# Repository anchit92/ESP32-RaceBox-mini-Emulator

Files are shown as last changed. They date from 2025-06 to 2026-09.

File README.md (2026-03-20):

# Open Source RaceBox Mini Emulator
> **Disclaimer:** This project is independent and open-source. It is not affiliated with, endorsed by, or officially connected to RaceBox. The name “RaceBox Mini” is used only to describe compatibility.

## Overview

This project provides firmware for an ESP32-based device that acts as a high-performance GPS/IMU Bluetooth Low Energy (BLE) broadcaster. It integrates a U-blox GNSS module for precise position, velocity, and timing data at 25Hz, along with an MPU6050 accelerometer and gyroscope for motion sensing.

The device is designed to be housed in a custom 3D-printed enclosure, with design files included in this repository.

---

> [!TIP]
> **Other Hardware Options**  
> Check Out The [Mods Folder](./Mods) For Other Hardware Options.
> For new builds, check out the [PCB version](./Mods/anchit92/PCB_version).

---

## Features

- **High-Resolution GPS Data**: Achieves 25Hz update rate using a U-blox GNSS module.  
- **Multi-Constellation Support**: Leverages GPS, Galileo, GLONASS, and BeiDou for enhanced accuracy and reliability.  
- **Integrated IMU**: Captures 3-axis accelerometer (`±8g`) and 3-axis gyroscope (`±500 deg/s`) data from the MPU6050.  
- **Real-time BLE Streaming**: Transmits a custom 88-byte data packet containing comprehensive GNSS and IMU information over BLE.  
- **Automatic Configuration**: Robust GPS initialization.
- **Custom RaceBox Protocol**: Data is encapsulated in a UBX-like custom protocol for efficient transmission.  
- **3D Printable Enclosure**: Includes design files for a compact and protective case.  

---

## Bill of Materials (BOM)

To build this project, you'll need the following components:

- **ESP32 Development Board**: (https://a.co/d/fTThpTl)  
- **U-blox GNSS Module**: 
  * MG-902 - https://a.co/d/b6DcUS6 
  * SAM-M10Q - https://a.co/d/54zrba3
  * MG-903 - https://a.co/d/fxp2tLk 
  * HGLRC M100-5883 - https://a.co/d/47V0TqJ
  * AERO SELFIE M10G-5883L- https://a.co/d/cmYLjBP (Theoretically works but I dont have it)
    
  Any M10 based U-blox modules should work, the output rate may vary but you should be able to get 25hz with just GPS enabled. But YMMV.
  
- **MPU6050 Accelerometer/Gyroscope Module**: (https://a.co/d/dCMwffg or similar)  
- **24AWG Hook-up Wire/Jumper Wires** or just use the wiring that comes with GNSS module, its perfect for this application.
- **M3x6 Screws** (2)    
- **Soldering Iron & Solder**
- **USB-C or Micro-USB Cable** (Depending on your ESP32 board, But USB-C all the things)  
- **3D Printer & ABS Filament**  

The electronics should cost under 40$. 

---

## Assembly Instructions

### Wire the Components, load the firmware and test them outdoors.

**ESP32 <--> U-blox GNSS Module:**
- ESP32 GPIO 16 (RX2) <--> GNSS TX  
- ESP32 GPIO 17 (TX2) <--> GNSS RX  
- ESP32 5V or 3.3V <--> GNSS VCC *(check voltage requirements)*  
- ESP32 GND <--> GNSS GND  

**ESP32 <--> MPU6050:**
- ESP32 GPIO 21 (SDA) <--> MPU6050 SDA  
- ESP32 GPIO 22 (SCL) <--> MPU6050 SCL  
- ESP32 5V or 3.3V <--> MPU6050 VCC *(check voltage requirements)*
- ESP32 GND <--> MPU6050 GND  

---

### Prepare the 3D Printed Case

- You shouldn't need any post processing of the printed parts but make sure the buttons slide smoothly in the holes in the lid

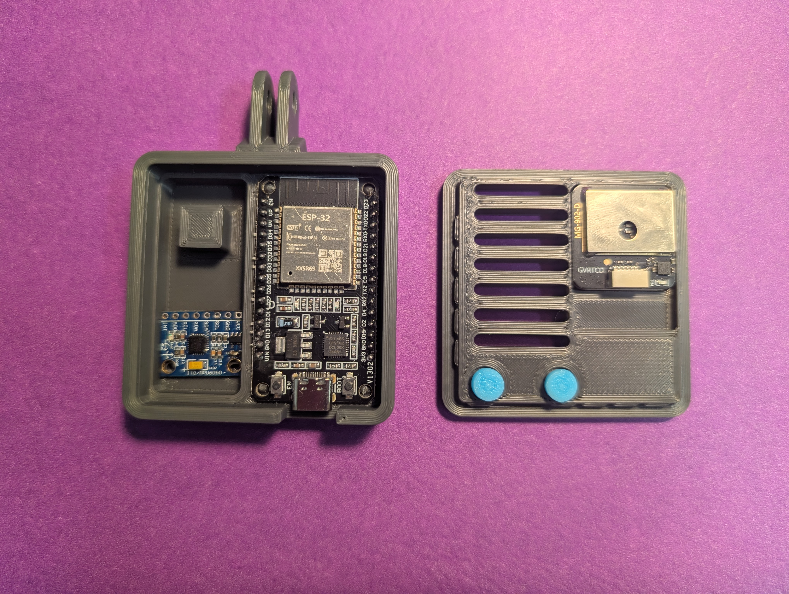
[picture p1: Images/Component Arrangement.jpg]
image info Component arrangement


### Enclose the Electronics

- Mount the MPU6050 module using M3 screws
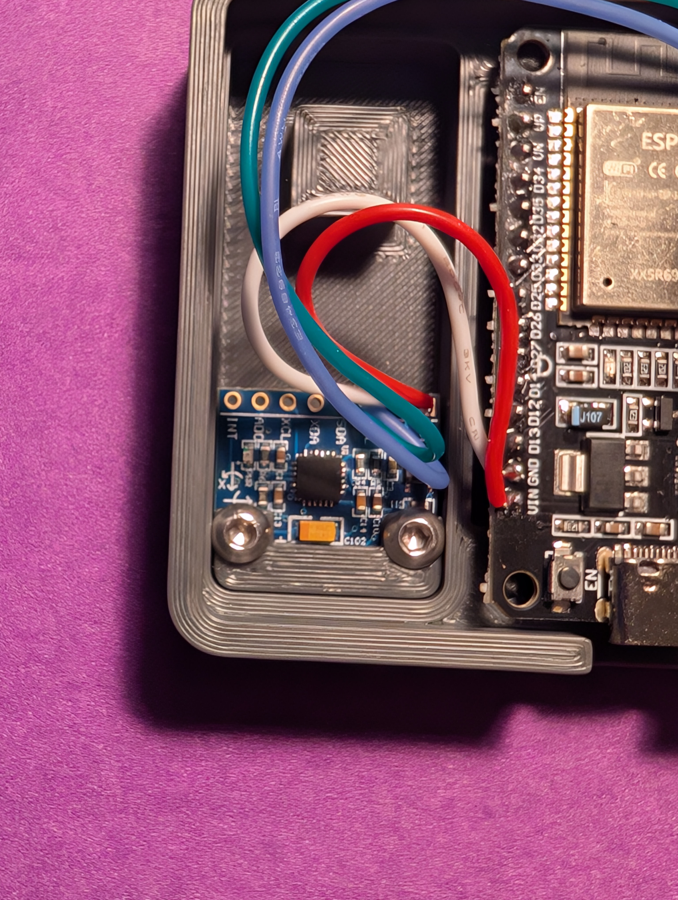
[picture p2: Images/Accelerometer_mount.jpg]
image info Wiring Guide

- Place the ESP32 in the slot  
- Route cables neatly
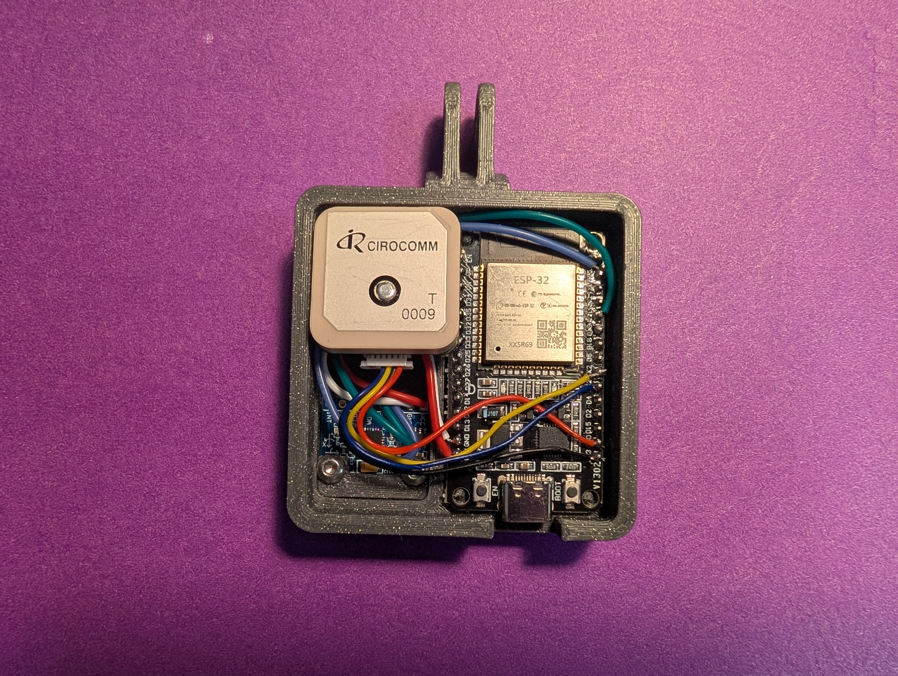
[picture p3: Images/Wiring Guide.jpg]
image info Wiring Guide

- Close the case carefully, it should click together. Make sure none of the wires are pinched or in the way of the buttons
GoPro mount version
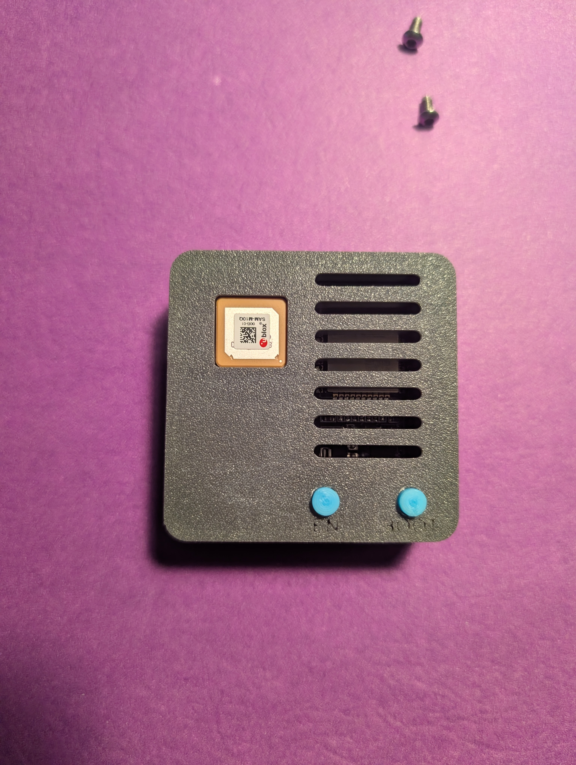
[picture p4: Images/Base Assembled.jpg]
Basic version


---

## Firmware Setup and Upload

### 1. Install Arduino IDE

Download from the [official Arduino website](https://www.arduino.cc/en/software).

### 2. Install ESP32 Board Support

- Open Arduino IDE Preferences  
- In “Additional Board Manager URLs” add: 
    - https://raw.githubusercontent.com/espressif/arduino-esp32/gh-pages/package_esp32_index.json

### 3. Install Libraries:
- Go to Sketch > Include Library > Manage Libraries... and install the following:
    - Adafruit MPU6050
    - Adafruit Unified Sensor
    - SparkFun u-blox GNSS Arduino Library (ensure it's version 2)

### 4. Open the Sketch: 
- Open the esp32_racebox_mini_emulator.ino in the Arduino IDE.
    - Configure Board Settings:
    - Go to Tools > Board and select your specific ESP32 board (e.g., "ESP32 Dev Module").
    - Ensure the correct Upload Speed and Port are selected.

### 5. Configure Firmware

* Update the GNSS constellations to use(lines 26-31).
  * For the SAM-M10Q module, I recommend using GPS and one local one, Galilieo should work great in most places. Selecting too many constellations can cause the update frequency to drop from 25Hz.
  * For the MG-902 module, you can select up to 4 constellations but it doesnt really make it more accurate than the SAM-M10Q module, but it doesnt appear to drop its frequency either, so might as well.

  https://app.qzss.go.jp/GNSSView/gnssview.html This could help you pick which constellations to pick.

* **OPTIONAL** – You may update the **10-digit number** in the `deviceName` on **line 33** to personalize your device.

    * **ID Limit:** If you intend to use this with the RaceBox App, The number must be **less than 4000000000**. The RaceBox app will not connect to devices with an ID of 4000000000 or higher.

    * **Prefix Requirement:** Make sure to **keep** the `"RaceBox Mini "` prefix unchanged—only change the numbers.

      ✅ **Correct:**
      `String deviceName = "RaceBox Mini 3999999999";`
    
      ❌ **Incorrect (Prefix changed):**
      `String deviceName = "MY GPS 6942069420";`
    
      ❌ **Incorrect (Number too high):**
      `String deviceName = "RaceBox Mini 4000000000";`

### 6. Upload the Firmware

* Click the **Upload** button (the right arrow icon) in the Arduino IDE to compile and upload the code to your ESP32.

  * If upload fails, try this sequence while the output shows "Connecting....":

    1. Hold the **BOOT** button
    2. Press and release the **EN** button
    3. Then release the **BOOT** button

* Open the **Serial Monitor** to verify startup. Initialization is complete when you see:

  BLE Packet Rate: 0.00 Hz | GNSS Update Rate: 25.00 Hz

  printed every 5 seconds.

## 3D Printed Enclosure

The repository includes `*.3mf` files for the custom 3D-printed enclosure designed specifically for the components in the BOM.

* 1x Base file.(either the GoPro mount version or the basic one to use with velcro)
* 1x Lid depending on the the type of GPS module you have.
* 2x Buttons (If you print a lid that supports buttons)
* 1x axdl_mount

Theres a Accelerometer blank included if you have a different accelerometer to create your own mount.

### Recommended Print Settings:

* **Material:** ABS (for durability and heat resistance, especially if used in a car)
* **Layer Height:** 0.2mm
* **Infill:** 15-20% (for sufficient strength)
* **Nozzle Temperature:** (Refer to your filament manufacturer's recommendations)
* **Bed Temperature:** (Refer to your filament manufacturer's recommendations)

## Usage

Once the firmware is uploaded and the device is powered on:

1.  The ESP32 will start advertising a BLE service named "**RaceBox Mini 0123456789**"(the devicename you customized before uploading the firmware).
2.  Use a compatible BLE client application to connect to the device.
    - Tested compatible apps, theoretically anything that supports a racebox mini should work.
        - Solostorm (Android)
        - RaceChrono (Android)
        - RaceChrono Pro (Android/iOS)
        - NMEAconnect (iOS)
        - AutoX DL(iOS)
        - Racebox App (Android/iOS)

## Contribution

Feel free to open issues or submit pull requests if you have suggestions, improvements, or bug fixes.

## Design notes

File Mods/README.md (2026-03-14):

# Mods & Additions

# List Of Mods

| Author | Mod Name | Description |
| --- | --- | --- |
| anchit92 |  [Battery Version](/Mods/anchit92/Battery_version/) | A battery powered version of the RaceBox Mini |
| anchit92 |  [PCB Version](/Mods/anchit92/PCB_version/) | An open-source custom PCB version of the RaceBox Mini |

# Information For Adding A Mod
Below is a quick summary of changes required for submitting a mod to the mods folder

## Table Structure
Information for updating the table for the addition/modification of a mod
- Put the name of the mod hyperlinked to the location of the mod in the repo
- A short single-sentence description of the mod
- Your name as the author

Example table entry: `| Your Name Here |  [Mod Folder Name](Link_To_Mod_Folder) | Short Description |`

## Folder Structure
Information for updating the `Mods` folder for the addition/modification of a mod

The `Mods` folder uses a 2 layer folder structure to organize all the mods
1. `Author Folder` - Top-level folder where all of an author's mods are
2. `Mod Folder` - The folder for an individual mod, which will be found in its relevant `Author Folder`

### Example Of Mod Folder Structure

| `Mods` Folder | `Author Folder` | `Mod Folder` |
| --- | --- | --- |
| Mods | Person 1 | Mod A From Person 1 |
|  |  | Mod B From Person 1 |
|  |  | Mod C From Person 1 |
|  | *Person 2 | *Mod D From Person 2 |
|  | Person 3 | Mod E From Person 3 |
|  |  | Mod F From Person 3 |

_*Note: If someone has a single mod it still has an author folder_

## What Must A Mod Folder Need To Include
At a bare minimum, each mod folder should contain a CAD file (_ideally a .step and/or .f3d file_), STLs (_ideally oriented correctly for printing_) a **screenshot from CAD or a photo** of the mod installed and a short `README.md` providing the relevant information for the mod

Also, make sure there are no spaces in any file or folder name (_using underscores `_` or dashes `-` where required_)

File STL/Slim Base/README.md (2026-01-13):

# Slim Base

50% lighter than the stock base and 6mm thinner. 

* Cut/ Desolder the pins on the esp32
* 1 M3x4

Follow same instructions as original. Dont use the little accelerometer spacer 

Struggle to fit the wires in without pinching them anywhere.

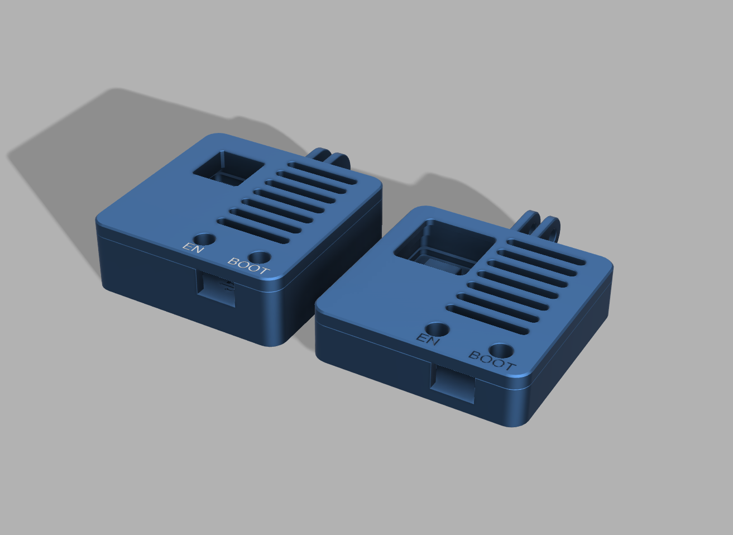
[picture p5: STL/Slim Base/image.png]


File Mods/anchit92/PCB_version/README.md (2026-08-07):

# RaceBox Mini Emulator - Custom PCB Version

[← Back to Main Repository](../../../)

## Overview
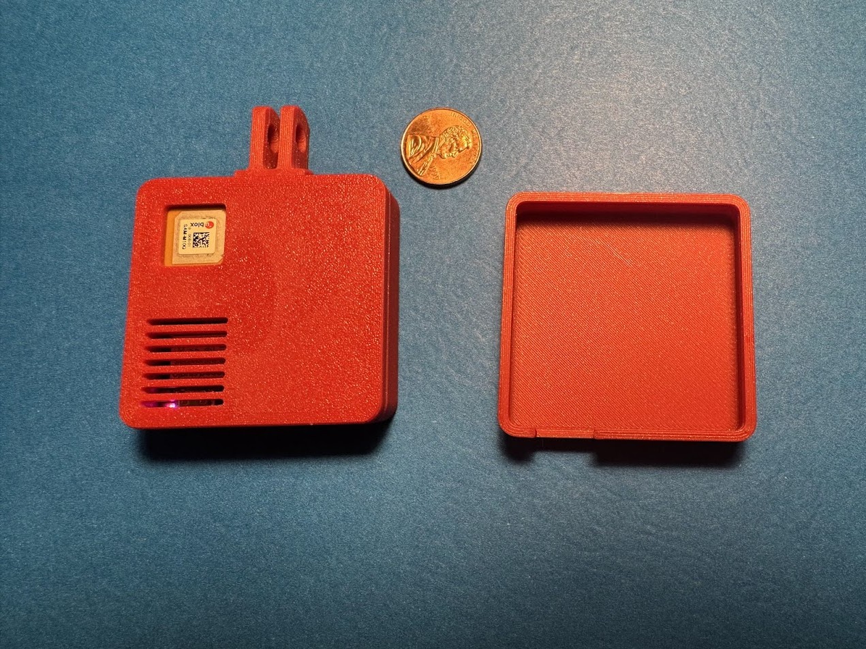
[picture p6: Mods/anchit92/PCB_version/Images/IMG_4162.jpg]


An open-source custom PCB and firmware project for a low-power, high-performance RaceBox Mini Emulator. 

**Why this version?** I created this custom PCB to learn PCB design, while standardizing on a single, reliable GNSS module (u-blox SAM-M10Q) and IMU (LSM6DS3) for better optimization and consistency across builds.

---

## Features

- **25Hz GNSS Data**: High-precision positioning using the u-blox SAM-M10Q module.
- **Integrated IMU**: Uses the onboard 6-axis IMU (LSM6DS3) of the XIAO Sense for "Shake-to-Wake" functionality.
- **Battery Powered**: Integrated battery charging and monitoring natively supported by the XIAO.
- **Ultra-Low Power Optimization**: Refined sleep modes achieving a ~40µA deep sleep baseline.
- **BLE Streaming**: Emulates the custom RaceBox protocol identically.
- **Custom PCB Integration**: Minimizes wiring and footprint size for a clean, stable build.

---

## Bill of Materials (BOM)

- **Microcontroller**: [Seeed Studio XIAO nRF52840 Sense](https://www.digikey.com/en/products/detail/seeed-technology-co-ltd/102010469/16652896)
- **GNSS Module**: [u-blox SAM-M10Q-00B](https://www.digikey.com/en/products/detail/u-blox/SAM-M10Q-00B/16672678)
- **Battery**: [1S 400mAh LiPo Battery](https://www.digikey.com/en/products/detail/adafruit-industries-llc/3898/9685336)
  - *Alternatively*, any LiPo battery up to 10mm tall, 25mm wide, and 40mm long should fit in the space in the case. (e.g., [Amazon Option](https://www.amazon.com/dp/B09F9VK77V?ref=ppx_yo2ov_dt_b_fed_asin_title))
  -*Alternatively* Search and pick a 802540 or 102540(untested) battery. They should all fit.
- **PCB**: [JLCPCB](https://www.jlcpcb.com/)
- **M3 Screw**: 1x M3 BHCS 4-6mm (for the pcb)
- **3D Printed Case**: Custom 3D printed case compatible with the PCB footprint.(you can get these manufactured at jlcpcb too, but I haven't tried that service from them)

Approximate Cost : $60

---

## PCB Manufacture

Use the fabrication files in `PCB_files/seeed_studio_GNSS/jlcpcb/production_files/` to order your assembled boards. 
- **Assembly Type**: Order all of them with "Economic" assembly on the **top side only** (the cost to do 2 or 5 is basically the same so dont bother skimping out).
- **Files**: The BOM file and the CPL file are included in the production files folder. 
- *Note: It should cost something like $7-$10 shipped for 5 boards. If the fabrication app quotes something like $40, it may be bugged—try refreshing or re-uploading the files.*

---

## Assembly & Wiring
If you order your PCB with JLCPCB SMT Assembly, note that having them include and solder the SAM-M10Q GNSS module is far too expensive. 

Therefore, **the board is specifically designed so that you can easily solder the GNSS module by hand**. You will need to:
1. Solder the **u-blox SAM-M10Q** GNSS module onto its designated footprint on the PCB. Note the orientation in the picture.
   - Align the package on the PCB.
   - Start with a single pin in one corner and fix it to the board. Then make sure it’s still aligned properly and do the same on the opposite corner.
   - Lots of flux all around, optionally use leaded solder to make this easier, then drag solder and inspect your joints, more flux and reflow as needed until you have no bridges and good joints on all the pins.
2. Solder the **Seeed Studio XIAO nRF52840 Sense** directly to the designated pads on the PCB using castellated mounting.
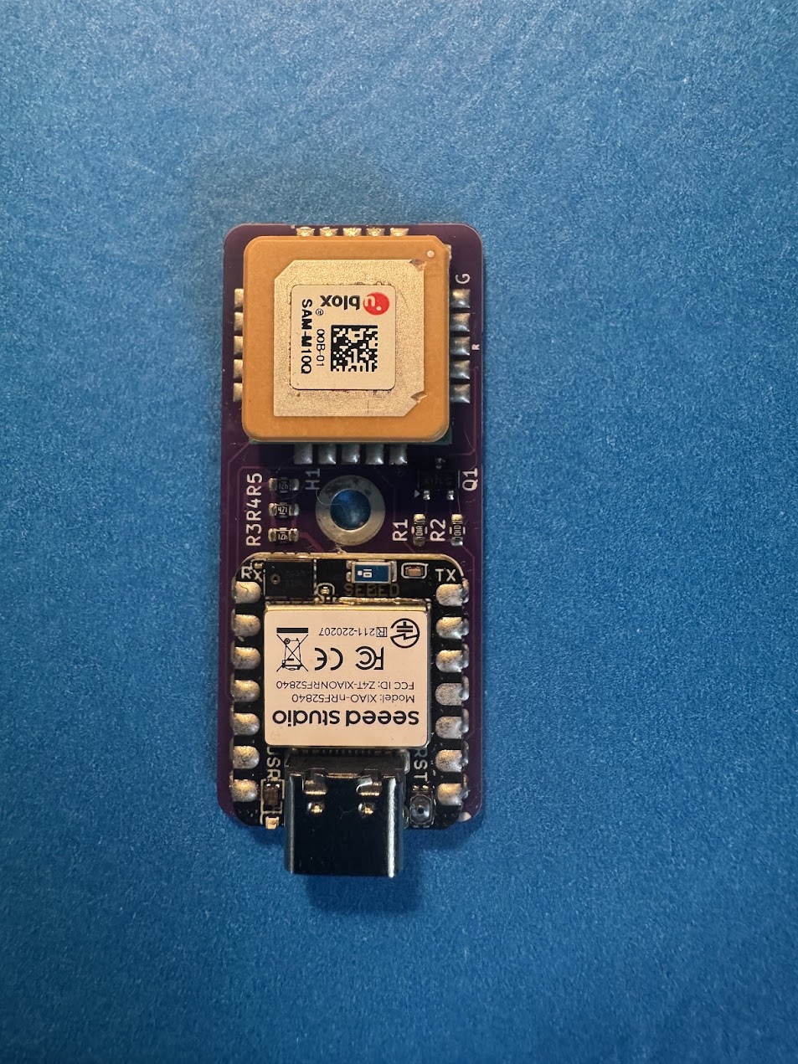
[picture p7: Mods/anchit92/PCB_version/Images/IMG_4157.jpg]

3. Solder the LiPo battery to the battery pads on the bottom of the XIAO.
4. Secure the battery to the case with double-sided tape/foam strips to prevent it from rattling around and snap the assembly together.
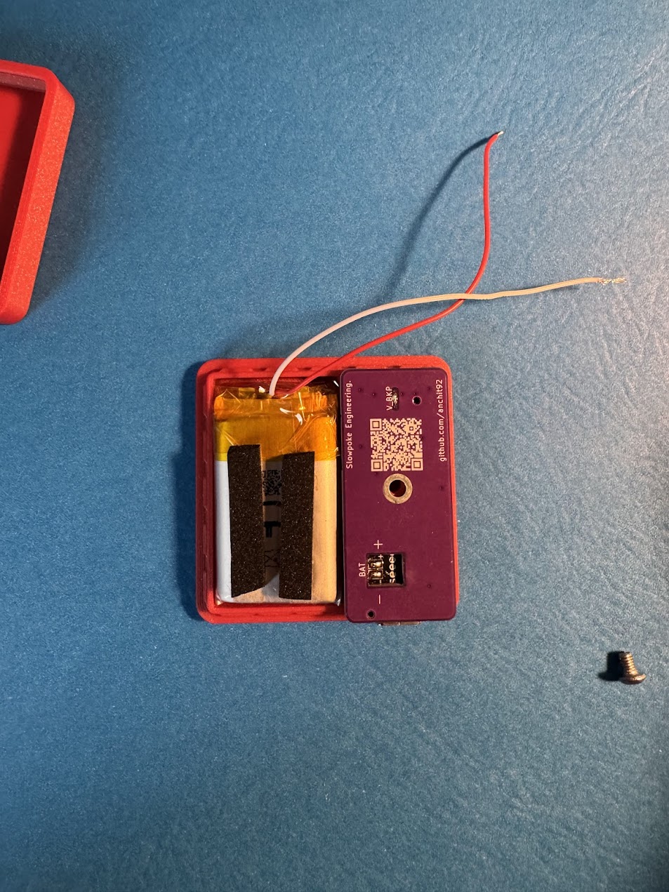
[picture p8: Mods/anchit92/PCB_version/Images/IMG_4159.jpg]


> [!NOTE]
> **Optional: V_BKP Cuttable Trace (Back of the board, v1.1+)**
> There is a `V_BKP` cuttable trace on the back of the custom PCB. **It is connected by default in v1.1**, keeping the GNSS module's backup RAM powered during sleep for a faster lock on wake-up.
> - **Connected (default):** Significantly faster GNSS lock times (reduces lock time from ~40 seconds down to ~10 seconds). Increases Light Sleep current from ~15µA up to 40-50µA.
> - **Cut:** Drops Light Sleep current back down to ~15µA at the cost of slower initial GNSS lock times.
> **Recommendation:** *Leave it connected.* Even with the larger ~50µA continuous draw, the device will effortlessly sit in standby for many months. The massive improvement in initial GPS lock times almost always outweighs holding onto extreme long-term battery life.

---

## Firmware Setup

### 1. Install Board Support
1.  Open Arduino IDE Preferences.
2.  Add `https://files.seeedstudio.com/arduino/package_seeeduino_boards_index.json` to "Additional Board Manager URLs".
3.  Go to **Tools > Board > Boards Manager**.
4.  Search for "Seeed nRF52" and install **Seeed nRF52 Boards**.
5.  Select **Seeed XIAO nRF52840 Sense** as your board.

### 2. Install Libraries
Install the following libraries via the Arduino Library Manager:
- **Seeed Arduino LSM6DS3** (for the onboard IMU)
- **SparkFun u-blox GNSS Arduino Library** (Version 2.x)
- **Adafruit TinyUSB**

### 3. Upload
1. **Confirm Soldering of SAM-M10Q**: After soldering the SAM-M10Q to the PCB, confirm that it is properly connected by loading the `GNSS_Debug_Passthrough/` sketch and checking for the output of NMEA sentences on the serial monitor.
2. **Burn OTP Settings**: Flash the `Code/M10_OTP_Burner/M10_OTP_Burner.ino` sketch to the nRF52840 to write the precise configurations to the SAM-M10Q (required for persistent 115200 baud communication across hardware reboots without battery backup and high performance mode for 25hz GNSS data).
3. **Flash Main Firmware**: Open `Code/nRF52840_racebox_mini_emulator_always_on/nRF52840_racebox_mini_emulator_always_on.ino` and upload it to your board to begin using it.
   - *Hardware Note:* The software logic natively handles the custom PCB requirements, such as inverse logic for the `GPS_EN_PIN` (pull LOW to enable) and optimal deep-power-down states. Ensure `#define PCB_VERSION` is uncommented in the `.ino` file if using this specific PCB.

---

## Customization

You can customize the firmware by modifying the `#define` lines at the top of the `.ino` file:

### 1. GNSS Constellations
Select which satellite systems to use. More systems = faster/better fix but slightly higher power usage and lower Refresh Rate.
```cpp
#define ENABLE_GNSS_GPS      // Always keep GPS enable
#define ENABLE_GNSS_GALILEO  // Recommended for best performance
// #define ENABLE_GNSS_GLONASS // Optional
// #define ENABLE_GNSS_BEIDOU  // Optional
```

### 2. Device Name
Personalize the BLE broadcast name (keep the "RaceBox Mini " prefix).
```cpp
#define SERIAL_NUM "0123456789" // The unique 10-digit serial
```

### 3. Sleep Timeout
Adjust how long the device waits before entering Light sleep after disconnection (default: 10 minutes).
```cpp
#define GPS_HOT_TIMEOUT_MS 900000 // 15 Minutes (Stay powered after disconnect)
```

### 4. Charging Behavior
Configure whether the device sleeps or stays active while charging.
```cpp
#define SLEEP_WHILE_CHARGING true // true = Efficiency (Sleeps), false = Performance (Always Active)
```

---

## Power Consumption & Runtime

- **Active Mode**: ~20mA - 40mA depending on fix / constellations.
- **Light Sleep** (BLE Advertising, GNSS Off): ~15µA (V_BKP cut) to 40-50µA (V_BKP connected, default)
  - Available in 'Always On' firmware / Configurable.
  - Default behavior for the PCB Version.
- **Deep Sleep** (System OFF, Wake-on-Shake): ~10µA - 40µA
  - *Theoretical Shelf Life*: >1 Year.

> [!NOTE]
> **LiPo Battery Caveats**:
> While the theoretical sleep runtime is years, real-world battery life is limited by:
> 1.  **Self-Discharge**: LiPo batteries lose ~2-5% of their charge per month even when disconnected.
> 2.  **Protection Circuit**: The battery's internal BMS consumes a small amount of power (2-10µA).
> 3.  **Temperature**: Extreme cold or heat significantly reduces effective capacity.
> 
> *Expect practically ~6-12 months of standby time in Deep Sleep.*

---

## Power Modes & Wake Functionality

This device supports two power-saving modes depending on the Configuration in the `.ino` file.

### 1. Light Sleep (Default Configuration)
**Behavior**: GNSS and IMU are powered down, but **BLE Advertising continues** (at a slower Eco rate).
**Usage**: Recommended for most users. Ensures the device is always discoverable and ready to connect instantly.
**Power**: ~15µA to ~50µA (depending on V_BKP cuttable trace). Both configurations offer amazing standby life. Theoretical standby on a standard 400mAh battery:
- **V_BKP cut (~15µA)**: ~1,111 days (~3 years)
- **V_BKP connected (~40-50µA, default in v1.1+)**: ~333 to ~416 days (~11-14 months)
*(Note: Real-world results will be lower due to battery self-discharge and BMS overhead, but in both cases, you will easily achieve many months of standby. **Leaving V_BKP connected is highly recommended** since ~11 months is more than enough time for most practical uses, and the vastly improved lock times are worth it.)*

**Trigger**:
- Occurs after GPS Hot Timeout after BLE disconnection. (default 15 minutes)

### 2. Deep Sleep (Optional Configuration)
**Behavior**: The device turns OFF completely (No BLE, No GNSS).
**Usage**: For extreme long-term storage where no BLE broadcast is desired.
**Configuration**:
- Enable by setting `#define ENABLE_DEEP_SLEEP true` in the firmware.
- Adjust `DEEP_SLEEP_DAYS` (default: 1 day) to automatically enter Deep Sleep after extended inactivity.
  
**Wake-Up**:
- **Shake-to-Wake**: The onboard accelerometer detects motion/taps and instantly wakes the device.
- **Plug-to-Wake**: Connecting USB power will also wake the device.

---

## Usage

1.  If using a battery it should always be powered on, If it in deep sleep, shake to to wake it up.
2.  The Blue LED on the XIAO will indicate BLE Connection (named "RaceBox Mini 0123456789" by default).
3.  Connect using a compatible app (RaceChrono, SoloStorm, etc.).
4.  **Charging**: The XIAO handles charging automatically when USB is connected. The green charge LED on the XIAO will light up while charging.
    - **Rate**: Fixed at **100mA**. Charging a dead 400mAh battery takes ~4-5 hours.
5.  The Red and Green LED on the XIAO will indicate the Fix Status of the GNSS Module.
    - Red: No Fix
    - Green: 3D Fix
    - Yellow: 2D Fix

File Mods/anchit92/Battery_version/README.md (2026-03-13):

# RaceBox Mini Emulator - Battery Version

[← Back to Main Repository](../../../)

## Overview

This is the battery-powered version of the RaceBox Mini Emulator, built around the **Seeed Studio XIAO nRF52840 Sense**. It represents a feature complete evolution of the project, correcting the technical debt of using EOL components in the original version.

It retains the high-performance 25Hz GNSS capabilities while adding native battery management, ultra-low power consumption, and a more compact form factor. This version leverages the **onboard LSM6DS3 IMU** of the XIAO nRF52840 Sense, eliminating the need for an external accelerometer/gyroscope module.

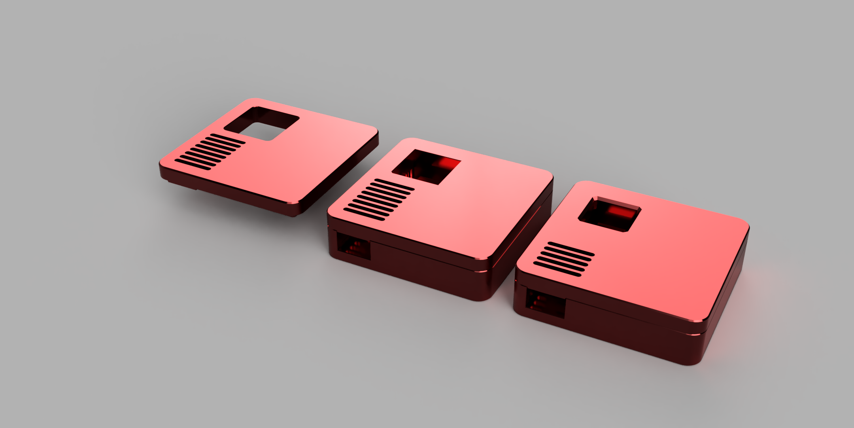
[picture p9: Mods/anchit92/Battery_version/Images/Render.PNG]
Render


### Assembled Unit
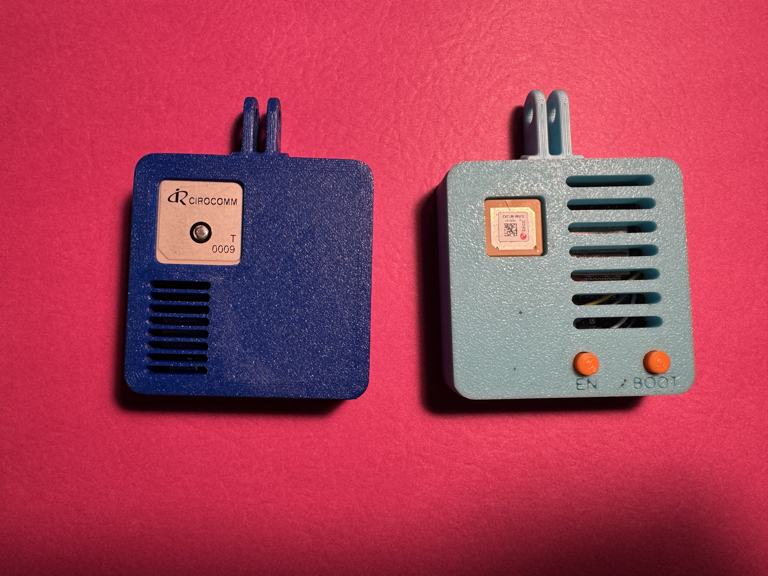
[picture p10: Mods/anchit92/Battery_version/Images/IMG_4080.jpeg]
Assembled Unit


---

## Features

- **25Hz GNSS Data**: High-precision positioning using U-blox GNSS modules.
- **Integrated IMU**: Uses the onboard 6-axis IMU (LSM6DS3) of the XIAO Sense.
- **Battery Powered**: Integrated battery charging and monitoring.
- **Compact Design**: Fits a standard LiPo battery (max 6.9mm x 54mm x 34mm).
- **Efficient Power**: Uses a TPS61023 boost converter for stable GNSS power.
- **BLE Streaming**: Same custom RaceBox protocol as the original.

## Bill of Materials (BOM)

- **Microcontroller**: [Seeed Studio XIAO nRF52840 Sense](https://www.digikey.com/en/products/detail/seeed-technology-co-ltd/102010469/16652896)
- **GNSS Module**: *All original modules are supported.* See, wiring notes about gps modules.
- **Power Management**: [TPS61023 Boost Converter](https://www.digikey.com/en/products/detail/adafruit-industries-llc/4654/12697636) (or similar 3.3V-to-5V/Adjustable boost module)
- **M3x4 Screw** (1)    
- **Battery**: 1S LiPo Battery.(Optional, your battery readings might be weird, But it works just fine) 
    - **Max Dimensions**: 6.9mm (H) x 54mm (L) x 34mm (W)
- **3D Printed Case**: Files located in `STL/` or `CAD/`.
- **Wires & Soldering Supplies**

---

## Assembly & Wiring

Stick down the battery with some dual sided tape. Something low strength but enough to prevent it from rattling.
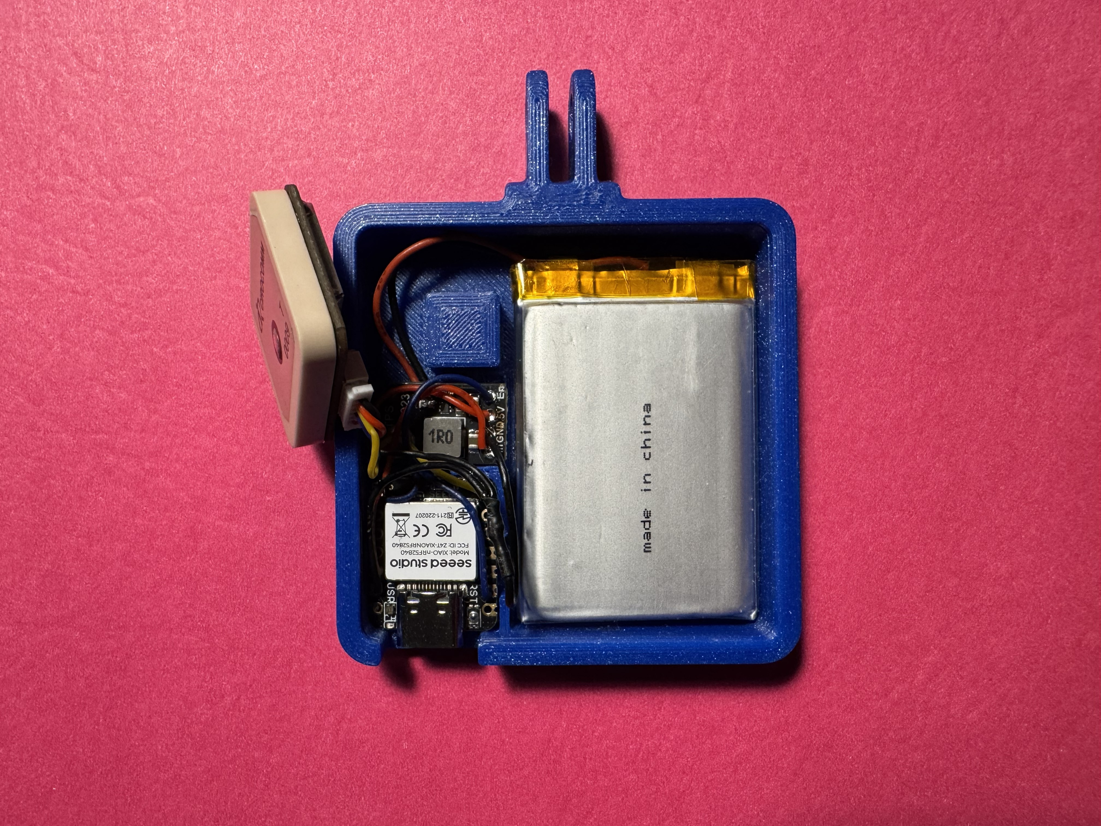
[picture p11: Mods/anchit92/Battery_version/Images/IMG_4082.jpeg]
Wiring Assembly


### Power Wiring

The GNSS module is powered via the TPS61023 boost converter:

#### TPS61023 Wiring:
To bypass the XIAO's internal 100mA regulator limit and prevent brownouts during GPS inrush:
1.  **XIAO BAT+** -> **TPS61023 VIN** -> BAT +
2.  **XIAO BAT-** -> **TPS61023 GND** -> BAT -
3.  **TPS61023 VOUT** -> **GNSS VCC**

### GNSS Data Wiring
- **XIAO D6 (TX)** -> **GNSS RX**
- **XIAO D7 (RX)** -> **GNSS TX**
- **XIAO GND** -> **GNSS GND**
- **XIAO D1** -> **TPS61023 EN**

> [!WARNING]
> **Power Supply Constraints **:
> High-performance GNSS modules can pull an inrush current spike of up to **100mA** during cold start or initialization. 
> The **Seeed Studio XIAO nRF52840 Sense** 3.3V voltage regulator is rated for a maximum of **100mA** when powered by battery.
> This leaves zero margin for the nRF52's own consumption (BLE, CPU peaks), which can lead to system brownouts or unstable GNSS initialization.
>
> So dont use the 3.3v rail to power the GPS, as tempting as that is.

*Note: The Onboard IMU relies on internal connections, so no external wiring is needed for the accelerometer/gyroscope.*

---

## Firmware Setup

The firmware is located in the `Code/nRF52840_racebox_mini_emulator` directory.

### 1. Install Board Support
1.  Open Arduino IDE Preferences.
2.  Add `https://files.seeedstudio.com/arduino/package_seeeduino_boards_index.json` to "Additional Board Manager URLs".
3.  Go to **Tools > Board > Boards Manager**.
4.  Search for "Seeed nRF52" and install **Seeed nRF52 Boards**.
5.  Select **Seeed XIAO nRF52840 Sense** as your board.

### 2. Install Libraries
Install the following libraries via the Arduino Library Manager:
- **Seeed Arduino LSM6DS3** (for the onboard IMU)
- **SparkFun u-blox GNSS Arduino Library** (Version 2.x)
- **Adafruit TinyUSB**

### 3. If using a SAM M10Q module(Optional)
Run the `Code/M10_OTP_Burner/M10_OTP_Burner.ino` Code before loading the main firmware to burn the high performance mode onto the gnss module.

### 3. Upload
**Note**: The firmware defaults to **Light Sleep** ("Always On") behavior for instant discoverability.

1.  Open `Code/nRF52840_racebox_mini_emulator_always_on/nRF52840_racebox_mini_emulator_always_on.ino`.
2.  Connect the XIAO via USB-C.
3.  Select the correct Port.
4.  Click **Upload**.

---

## Customization

You can customize the firmware by modifying the `#define` lines at the top of the `.ino` file:

### 1. GNSS Constellations
Select which satellite systems to use. More systems = faster/better fix but slightly higher power usage.
```cpp
#define ENABLE_GNSS_GPS      // Always keep GPS enable
#define ENABLE_GNSS_GALILEO  // Recommended for best performance
// #define ENABLE_GNSS_GLONASS // Optional
// #define ENABLE_GNSS_BEIDOU  // Optional
```

### 2. Device Name
Personalize the BLE broadcast name (keep the "RaceBox Mini " prefix).
```cpp
#define SERIAL_NUM "0123456789" // The unique 10-digit serial
```

### 3. Sleep Timeout
Adjust how long the device waits before entering Light sleep after disconnection (default: 10 minutes).
```cpp
#define GPS_HOT_TIMEOUT_MS 600000 // 10 Minutes (Stay powered after disconnect)
```

### 4. Charging Behavior
Configure whether the device sleeps or stays active while charging.
```cpp
#define SLEEP_WHILE_CHARGING true // true = Efficiency (Sleeps), false = Performance (Always Active)
```

## Power Consumption & Runtime
Tested with this **[1100mAh LiPo Battery](https://a.co/d/hiqOe05)**:

- **Active Mode**: ~14 Hours (Observed)
  - *Current Draw*: 50-80mA (dependent on GNSS Constellations and Model of GNSS Module)
- **Light Sleep** (BLE Advertising, GNSS Off): ~100µA
  - Available in 'Always On' firmware / Configurable.
  - Default behavior for Battery Version.
- **Deep Sleep** (System OFF, Wake-on-Shake): < 10µA
  - *Theoretical Shelf Life*: >1 Year.

> [!NOTE]
> **LiPo Battery Caveats**:
> While the theoretical sleep runtime is years, real-world battery life is limited by:
> 1.  **Self-Discharge**: LiPo batteries lose ~2-5% of their charge per month even when disconnected.
> 2.  **Protection Circuit**: The battery's internal BMS consumes a small amount of power (2-10µA).
> 3.  **Temperature**: Extreme cold or heat significantly reduces effective capacity.
> 
> *Expect practically ~6-12 months of standby time in Deep Sleep.*

---

## Power Modes & Wake Functionality

This device supports two power-saving modes depending on the Configuration in the `.ino` file.

### 1. Light Sleep (Default Configuration)
**Behavior**: GNSS and IMU are powered down, but **BLE Advertising continues** (at a slower Eco rate).
**Usage**: Recommended for most users. Ensures the device is always discoverable and ready to connect instantly.
**Power**: ~100µA — Low power consumption for daily usage (months of standby).

**Trigger**:
- Occurs after GPS Hot Timeout after BLE disconnection. (default 10 minutes)

### 2. Deep Sleep (Optional Configuration)
**Behavior**: The device turns OFF completely (No BLE, No GNSS).
**Usage**: For extreme long-term storage where no BLE broadcast is desired.
**Configuration**:
- Enable by setting `#define ENABLE_DEEP_SLEEP true` in the firmware.
- Adjust `DEEP_SLEEP_DAYS` (default: 1 day) to automatically enter Deep Sleep after extended inactivity.
  
**Wake-Up**:
- **Shake-to-Wake**: The onboard accelerometer detects motion/taps and instantly wakes the device.
- **Plug-to-Wake**: Connecting USB power will also wake the device.

---

## Usage

1.  If using a battery it should always be powered on, If it in deep sleep, shake to to wake it up.
2.  The Blue LED on the XIAO will indicate BLE Connection (named "RaceBox Mini 0123456789" by default).
3.  Connect using a compatible app (RaceChrono, SoloStorm, etc.).
4.  **Charging**: The XIAO handles charging automatically when USB is connected. The green charge LED on the XIAO will light up while charging.
    - **Rate**: Fixed at **100mA**. Charging a dead 1100mAh battery takes ~11-12 hours due to losses.
5.  The Red and Green LED on the XIAO will indicate the Fix Status of the GNSS Module.
    - Red: No Fix
    - Green: 3D Fix
    - Yellow: 2D Fix

---

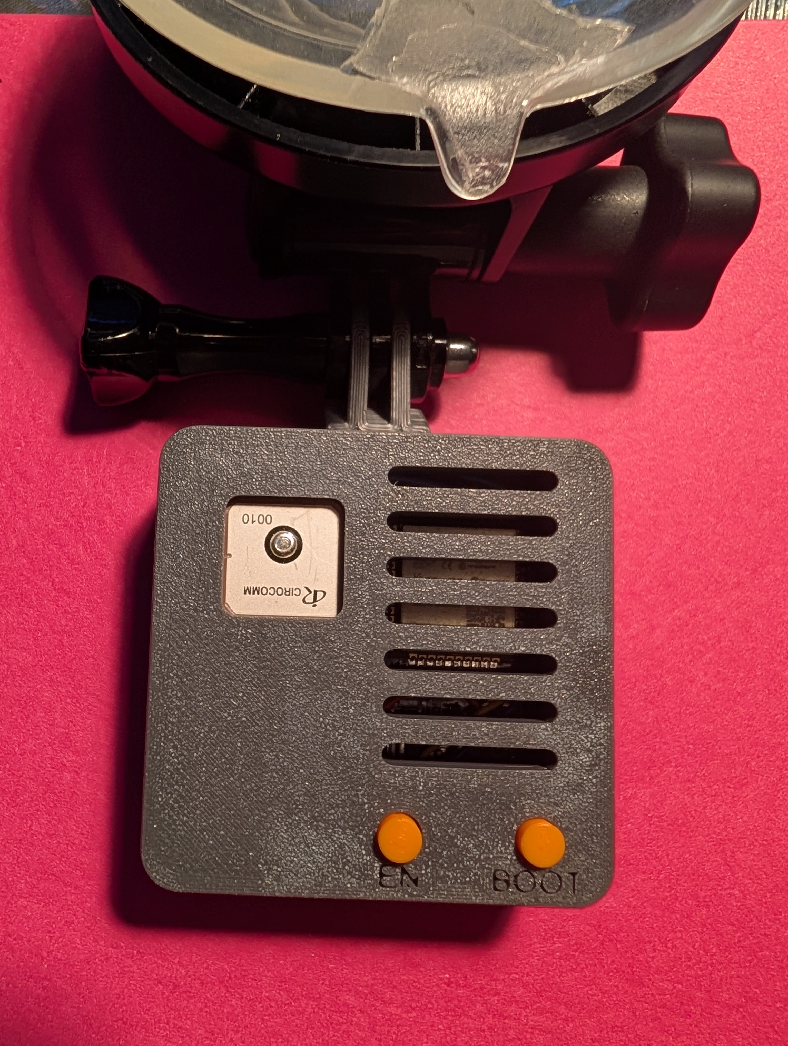
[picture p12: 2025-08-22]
Images/18mm Antenna GPS.jpg

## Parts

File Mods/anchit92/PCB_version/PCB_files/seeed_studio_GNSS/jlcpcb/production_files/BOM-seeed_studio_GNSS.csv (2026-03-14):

Comment | Designator | Footprint | LCSC | Quantity
100 | R1 | R_0603_1608Metric | C22775 | 1
100k | R2 | R_0603_1608Metric | C25803 | 1
470 | R3,R4,R5 | R_0603_1608Metric | C23179 | 3
AO3401A | Q1 | SOT-23 | C15127 | 1

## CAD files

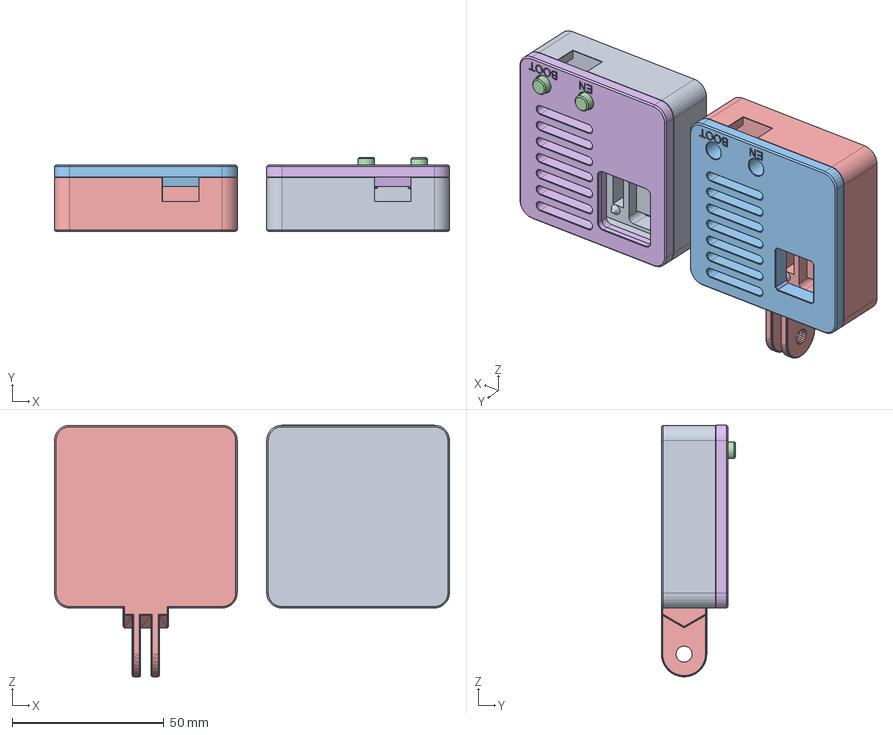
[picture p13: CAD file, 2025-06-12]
CAD/ESP32 RACEBOX v9.step
130.3 x 24.5 x 83.0 mm
Base
axdl mount
Lid 16mm gps
Button 1
Button 2
Base with gopro mount
Lid 25mm gps
Accelormeter blank

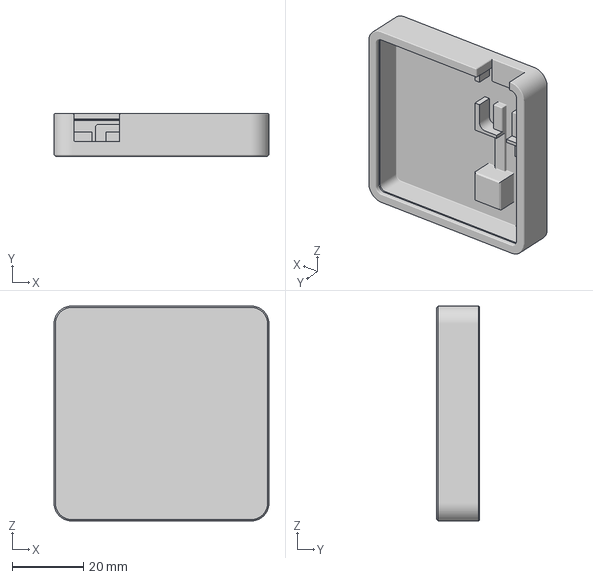
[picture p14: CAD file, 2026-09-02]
Mods/anchit92/Battery_version/STL/Base.3mf
60.3 x 12.0 x 60.3 mm

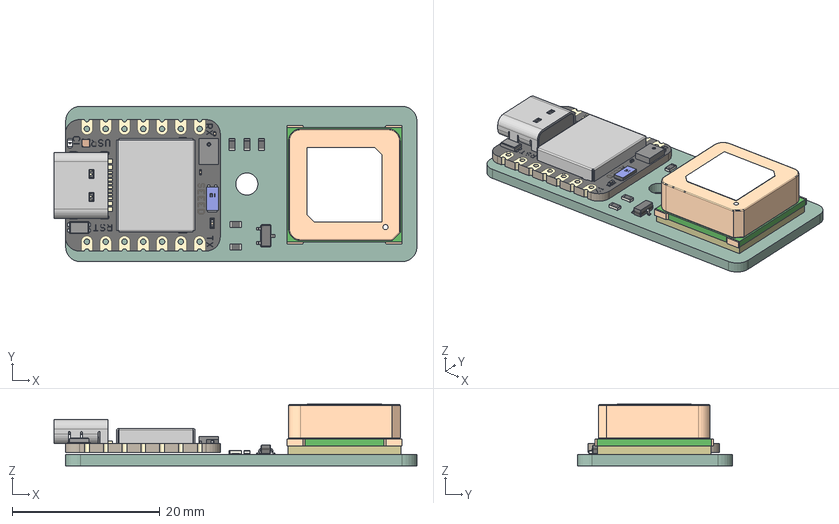
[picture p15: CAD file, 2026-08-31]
Mods/anchit92/PCB_version/CAD/DIY Racebox Emulator PCB.step
49.1 x 21.0 x 8.33 mm
R_0603_1608Metric x 5
SOT-23
seeed_studio_GNSS_PCB
SAM-M10Q-00B
BOSS-EXTRUDE14_8_
BOSS-EXTRUDE7_4_
BOSS-EXTRUDE7_3_
BOSS-EXTRUDE14_4_
BOSS-EXTRUDE14_2_
BOSS-EXTRUDE14_11_
BOSS-EXTRUDE7_7_
BOSS-EXTRUDE14_9_
BOSS-EXTRUDE14_3_
BOSS-EXTRUDE14_7_
MIRROR2
BOSS-EXTRUDE14_5_
BOSS-EXTRUDE14_12_
BOSS-EXTRUDE7_8_
BOSS-EXTRUDE7_1_
BOSS-EXTRUDE14_10_
BOSS-EXTRUDE7_9_
BOSS-EXTRUDE14_6_
BOSS-EXTRUDE14_1_
BOSS-EXTRUDE7_6_
BOSS-EXTRUDE7_2_
CUT-EXTRUDE5
BOSS-EXTRUDE7_5_
Shield
Pins
CAP x 2
ANT1
Silkscreen
CAP 3
LED
USR
MSM261D3526H1CPM

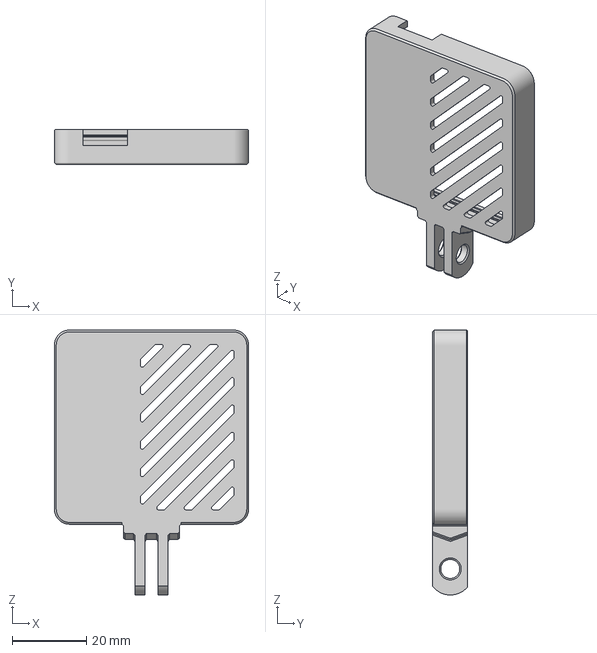
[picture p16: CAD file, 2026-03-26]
Mods/anchit92/PCB_version/STL/GoPro Base Vented.3mf
52.2 x 9.50 x 71.2 mm

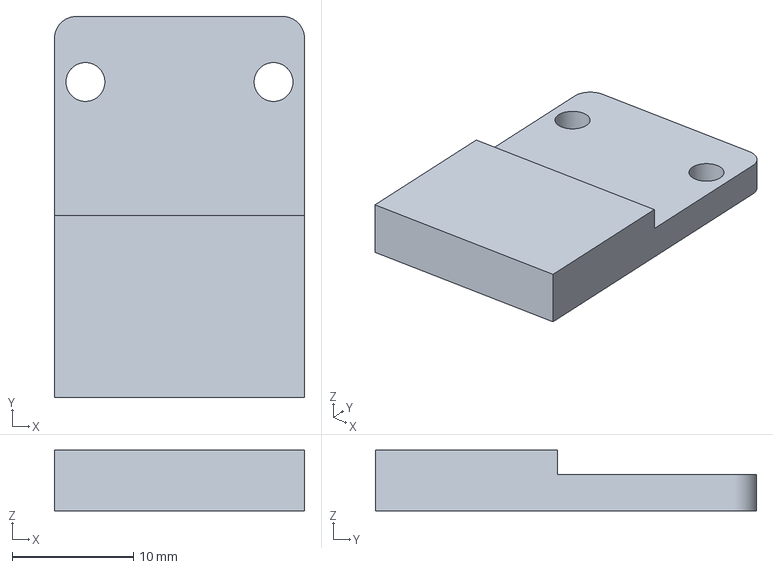
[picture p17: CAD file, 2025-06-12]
STL/Accelormeter blank.3mf
20.6 x 31.4 x 5.00 mm

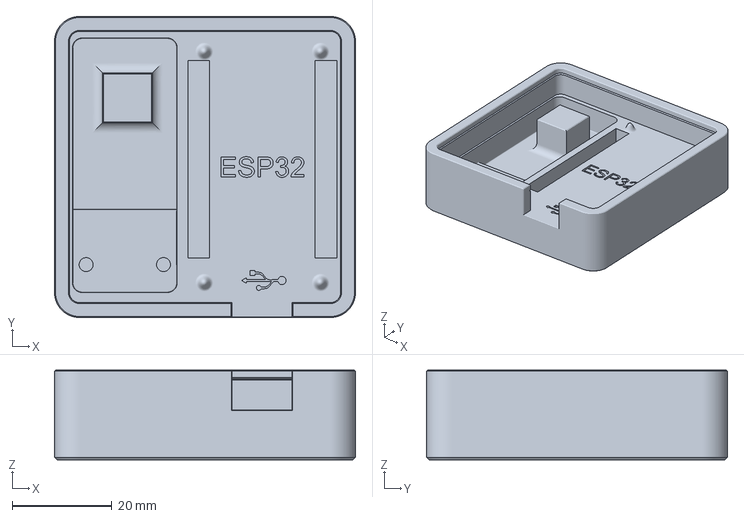
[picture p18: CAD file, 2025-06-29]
STL/Base/Base.3mf
60.3 x 60.3 x 18.0 mm

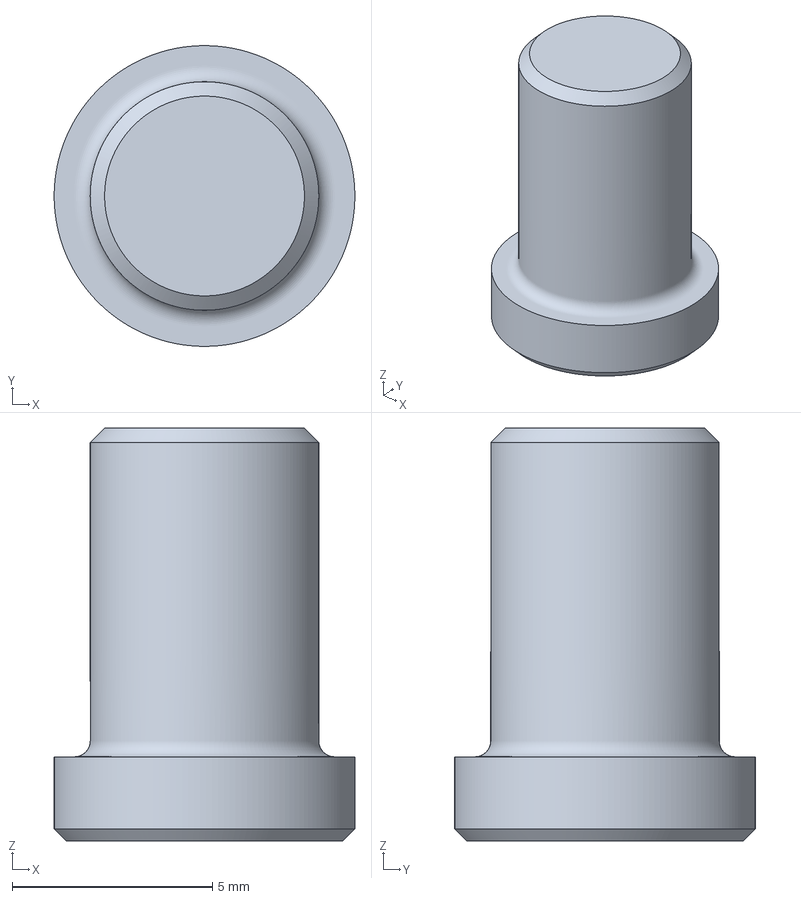
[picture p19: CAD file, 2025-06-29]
STL/Buttons/Button_x2.3mf
7.50 x 7.50 x 10.3 mm

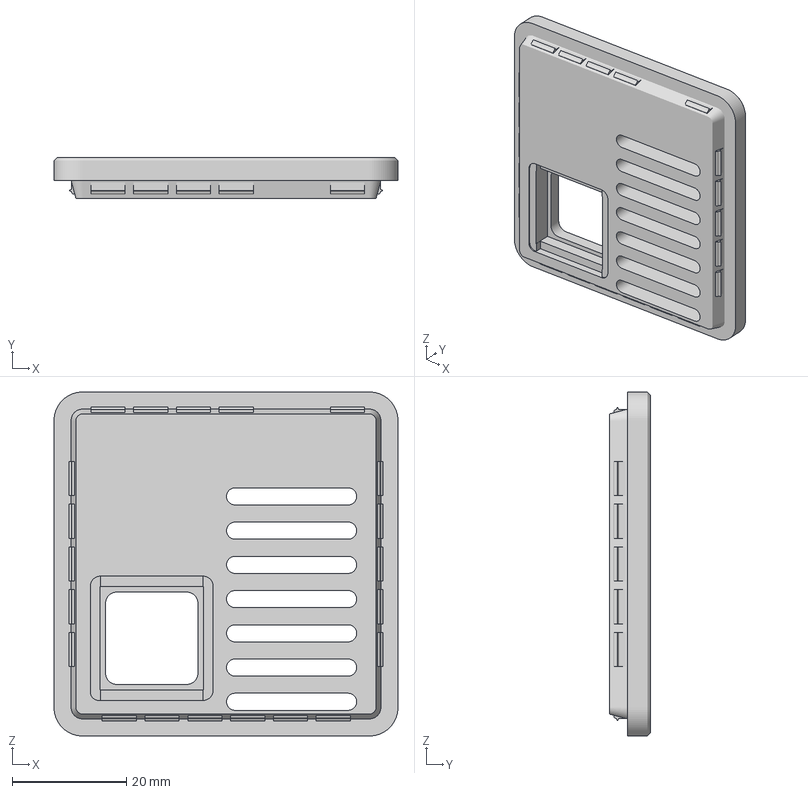
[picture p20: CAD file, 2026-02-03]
STL/Lids/Lid HGLRC M100-5883 No Buttons.3mf
60.3 x 7.10 x 60.3 mm

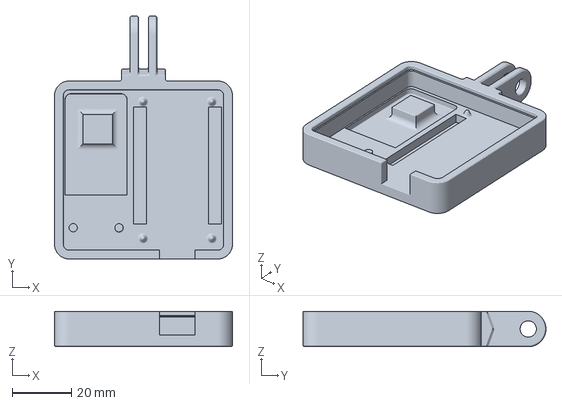
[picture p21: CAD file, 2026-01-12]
STL/Slim Base/Slim Base GoPro.3mf
60.3 x 82.3 x 12.0 mm

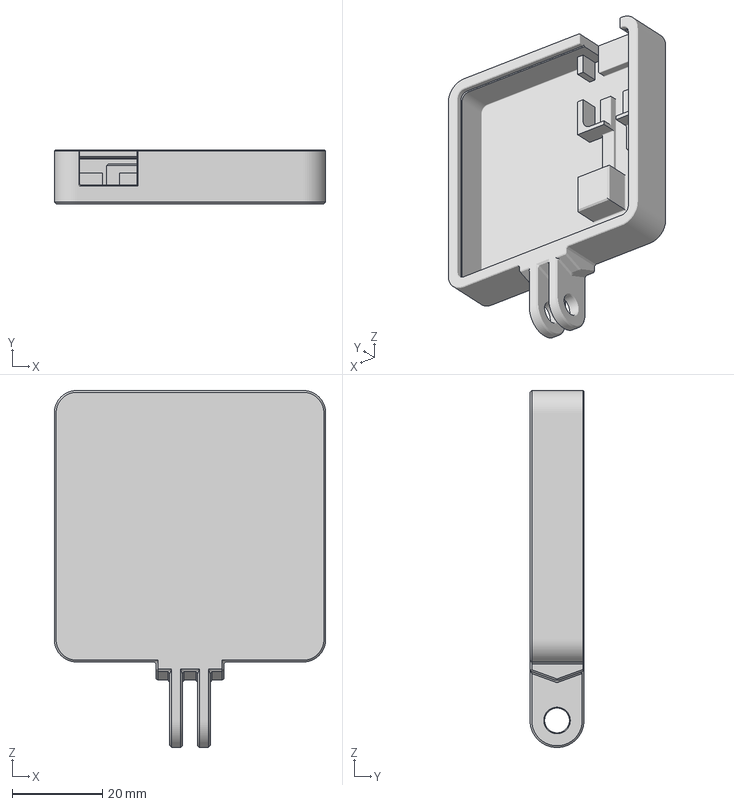
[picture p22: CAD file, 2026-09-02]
Mods/anchit92/Battery_version/STL/GoPro Base.3mf
60.3 x 12.0 x 79.3 mm

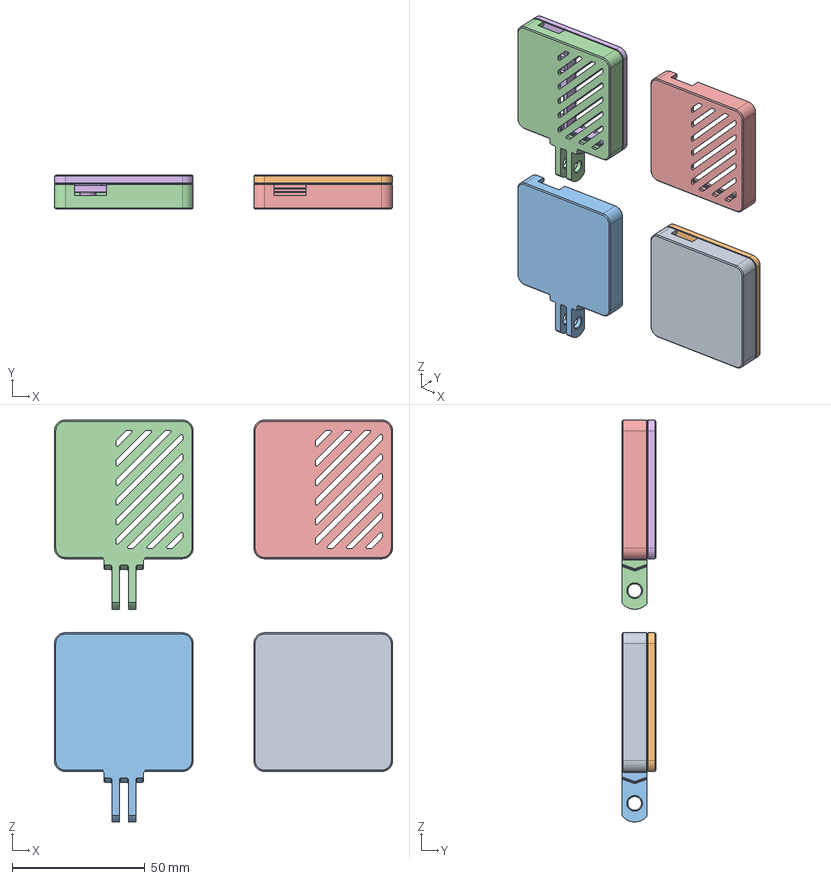
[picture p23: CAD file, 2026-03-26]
Mods/anchit92/PCB_version/CAD/PCB RACEBOX.step
127.2 x 12.9 x 151.2 mm
Base
Lid 25mm gps
Base_1
GoPro Base (1)
Base (1)
Lid (1)

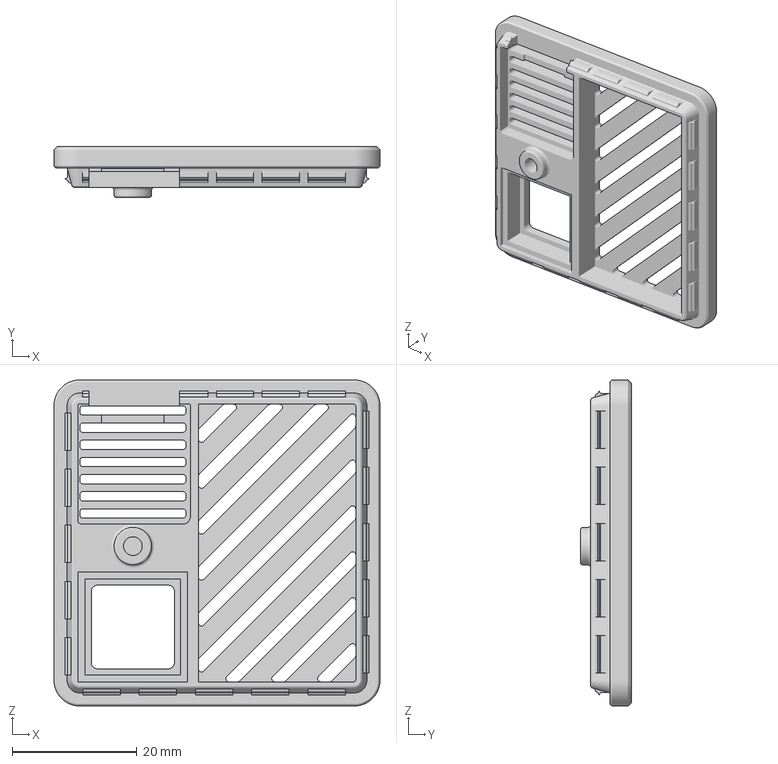
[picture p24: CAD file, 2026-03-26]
Mods/anchit92/PCB_version/STL/Lid vented.3mf
52.2 x 8.10 x 52.2 mm

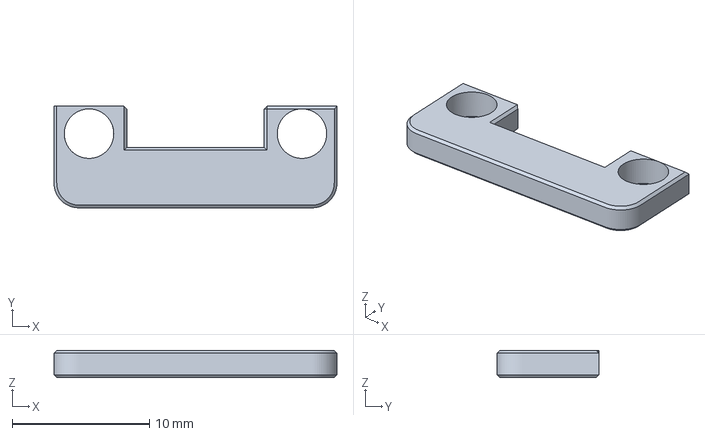
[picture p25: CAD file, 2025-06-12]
STL/AXDL_mount.3mf
20.6 x 7.40 x 2.00 mm

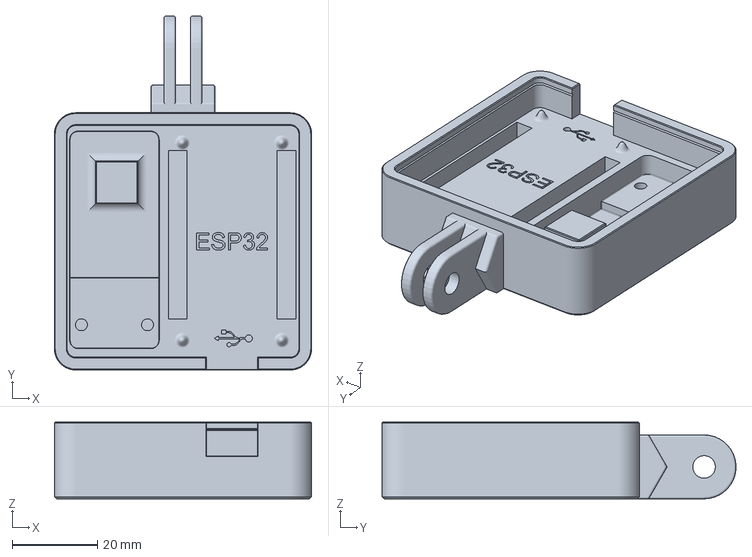
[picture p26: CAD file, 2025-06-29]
STL/Base/Base_GoPro_mount.3mf
60.3 x 83.0 x 18.0 mm

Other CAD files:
STL/Buttons/More_Clearance_Button_x2.3mf
STL/Lids/Lid HGLRC M100-5883.3mf
STL/Slim Base/Slim Base.3mf
Mods/anchit92/Battery_version/STL/Lid HGLRC M100-5883 gps.3mf
Mods/anchit92/Battery_version/CAD/nRF52840 RACEBOX.step
Mods/anchit92/Battery_version/STL/Lid MG-902 gps.3mf
Mods/anchit92/Battery_version/STL/Lid MG-903 gps.3mf
Mods/anchit92/Battery_version/STL/Lid SAM-M10Q gps.3mf
Mods/anchit92/PCB_version/STL/Base vented.3mf
Mods/anchit92/PCB_version/STL/Base.3mf
Mods/anchit92/PCB_version/STL/GoPro Base.3mf
Mods/anchit92/PCB_version/STL/Lid.3mf
STL/Lids/Lid MG-903 gps no buttons.3mf
STL/Lids/Lid MG-903 gps.3mf
STL/Lids/Lid_MG-902_GPS.3mf
STL/Lids/Lid_MG-902_GPS_No_Buttons.3mf
STL/Lids/Lid_SAM-M10Q_GPS.3mf
STL/Lids/Lid_SAM-M10Q_GPS_No_Buttons.3mf

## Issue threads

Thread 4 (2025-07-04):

Compiling Error

abarks123, 2025-07-04:
I am very new to this and trying to follow your directions exactly.  In your in README under Firmware Setup and Upload I have followed all the sets but when I hit upload I get the following error:

In file included from c:\Users\abark\OneDrive\Documents\Arduino\libraries\ESP32_BLE_Arduino\src/BLEAdvertising.h:15,
                 from c:\Users\abark\OneDrive\Documents\Arduino\libraries\ESP32_BLE_Arduino\src/BLEServer.h:19,
                 from c:\Users\abark\OneDrive\Documents\Arduino\libraries\ESP32_BLE_Arduino\src/BLEDevice.h:18,
                 from C:\Users\abark\Downloads\esp32_racebox_mini_emulator\esp32_racebox_mini_emulator.ino:6:
c:\Users\abark\OneDrive\Documents\Arduino\libraries\ESP32_BLE_Arduino\src/FreeRTOS.h:61:35: error: 'ringbuf_type_t' has not been declared
   61 |         Ringbuffer(size_t length, ringbuf_type_t type = RINGBUF_TYPE_NOSPLIT);
      |                                   ^~~~~~~~~~~~~~
Multiple libraries were found for "BLEDevice.h"
  Used: C:\Users\abark\OneDrive\Documents\Arduino\libraries\ESP32_BLE_Arduino
  Not used: C:\Users\abark\AppData\Local\Arduino15\packages\esp32\hardware\esp32\3.2.1\libraries\BLE
exit status 1

Compilation error: exit status 1

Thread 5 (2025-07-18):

BLEDevice library confusion

nbdnnm, 2025-07-18:
Hi @anchit92
I was installing the libraries described in 3. Install Libraries section and found only ESP32 BLE Arduino in the list of available libs.

I installed it, and when I pressed verify, I got

```
ESP32-RaceBox-mini-Emulator/Code/esp32_racebox_mini_emulator/esp32_racebox_mini_emulator.ino:6:
ESP32_BLE_Arduino/src/FreeRTOS.h:61:35: error: 'ringbuf_type_t' has not been declared
   61 |         Ringbuffer(size_t length, ringbuf_type_t type = RINGBUF_TYPE_NOSPLIT);
      |                                   ^~~~~~~~~~~~~~

/ESP32-RaceBox-mini-Emulator/Code/esp32_racebox_mini_emulator/esp32_racebox_mini_emulator.ino:58:47: error: conversion from 'std::string' {aka 'std::__cxx11::basic_string<char>'} to non-scalar type 'String' requested
   58 |     String rxValue = pCharacteristic->getValue();
      |                      ~~~~~~~~~~~~~~~~~~~~~~~~~^~
Multiple libraries were found for "BLEDevice.h"
  Used: /Arduino/libraries/ESP32_BLE_Arduino
  Not used: /Library/Arduino15/packages/esp32/hardware/esp32/3.2.1/libraries/BLE
exit status 1

Compilation error: conversion from 'std::string' {aka 'std::__cxx11::basic_string<char>'} to non-scalar type 'String' requested
```

I have googled and found that there are conflicts, and just removed ESP32 BLE Arduino

Then it was compiled successfully.

Would it be good to add a remark to the README clarifying this point?

anchit92, 2025-07-18:
i could have sworn i updated the documentation after the last time-
resolved in commit eee7781e18915d024a9c7d5349a513a033c4b083

Closed 2025-07-18.

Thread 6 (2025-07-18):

Device calibration

nbdnnm, 2025-07-18:
Hi @anchit92

I have the original RaceBox mini S, and the app has an option to calibrate it before usage.

AFAIU, it is needed to accelerate/gyroscope data to be correct.

I couldn't find anything about this point in the README

How does it work with your emulator?

If it is preconfigured, would it make sense to position the sensor in the box in a certain way and add a picture of a car and an arrow on the cap to help people position the box correctly in a car?

anchit92, 2025-07-19:
Let me know if you have issues with any particular app. I'm leaving this open for a bit and will close it if there's no activity on this.

nbdnnm, 2025-07-19:
Yes, I forgot that there is a calibrate button in RaceChrono as well.
It works
thanks

anchit92, 2025-07-20:
I thought about that, but smoothing introduces a little latency, Check if the code in the this branch works -

https://github.com/anchit92/ESP32-RaceBox-mini-Emulator/tree/feature/IMU_with_smoothing

 I don't want to merge into master without running the code for a few events, and i haven't had a chance to do that.

nbdnnm, 2025-07-20:
I agree that latency is worse than comfort during calibration.
It's easier just to put a remark into the docs.

I left the device for a test to my fellow racer.
I will check the another version later when I have it.

anchit92, 2025-07-21:
Little Testing around calibration-
The code in master calibrates on racechrono in most cases for me, i tried it inside a couple of cars and only my FRS turned on is too noisy for racechrono to calibrate. The M2/Civic are smooth enough on for it to not matter, this indicates the smoothing is borderline.

But that's irrelevant because it should work in FRS because that platform is the prototypical autocross car.

The code with the smoothing calibrates in racechrono everywhere but I'm still not convinced that should go into master. I've been thinking about this but I'm pretty sure the adafruit library and the imu have some smoothing built in and i think i should see if there's a way to configure that instead of adding a layer of smoothing on top of what they do, The latency introduced is very noticeable to my eye.

anchit92, 2025-07-22:
This is fixed in https://github.com/anchit92/ESP32-RaceBox-mini-Emulator/tree/feature/Klaman_filter_IMU

Let me know if you have issues with the code in that branch. You'll have to install the SimpleKalmanFilter library to use that code-

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

I'll merge the related PR after running it through some events. This also includes the GNSS fixes.

Closed 2025-07-20.

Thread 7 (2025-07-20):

Alternative lid

nbdnnm, 2025-07-20:
Hi there,

Would it be possible to add another lid without button holes and writings?

I understand that the buttons are very helpful for debugging purposes, but I suppose in many cases, they would be assembled once and used as is without any modifications.

nbdnnm, 2025-07-20:
hm, looks like it is not very complicated to make it myself
I just never tried 3d modelling before, but I managed to close these holes and letters in a Tinkercad
I will try to make a PR for this change if you don't mind adding it

anchit92, 2025-07-20:
resolved in 669df8fa06819c96dc67a3180dc06579ae5e36ab

nbdnnm, 2025-07-20:
you didn't give me a chance ! :)
anyway, thank you!

Closed 2025-07-20.

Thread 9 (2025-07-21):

GNSS frequency clarification in README

nbdnnm, 2025-07-21:
Hi @anchit92

I have assembled the kit with SAM-M10Q and noticed that it shows a 12Hz rate in RaceChrono when the original RaceBox mini always gives 25Hz.
AFAIU, it impacts the precision of the positioning.
I used it because you mentioned in the readme that this is the newer chip, and I thought it would be better.

Disassembling the original RaceBox mini shows that it uses the older chip, MG-902 (on some metal foil, probably antenna?), and some other GNSS chip.

Do you know if MG-902 give this rate, or is it because of a combination with the antenna and another chip?

WDYT would that make sense to add to the doc?

anchit92, 2025-07-21:
@nbdnnm I think i may have more regarding this issue, Could you confirm how many satellites you're getting when you get low update frequency?

After a couple of hours of uptime and depending on the time of the day you can get a lock on over 20 satellites, I can confirm that the update frequency starts fluctuating once that happens, the update frequency drops immediate at a lock of 20 satellites to about 12-13hz.

The 2 modules appear to handle this differently, i don't get 20 satellites on the MG-902 and it keeps a more stable update frequency. the  SAM-M10Q module will acquire more satellites and cause the update frequency issue.

The difference in accuracy between 16 GPS+Galileo satellites and 20 GPS+Galileo+GLONASS+BEIDOU satellites appears to be less than 10 cm. So the recommendation needs to be enable GPS+1 preferred gnss constellation depending on where you're located
https://app.qzss.go.jp/GNSSView/gnssview.html

That needs a little bit of a restructure of the code to implement.

anchit92, 2025-07-21:
or maybe we're running into the bandwidth limit of the 115200 baud rate?

anchit92, 2025-07-22:
Its not baud rate limited, doubled the bandwidth and it made no difference, Its weird, just GPS and Galileo with 16 satellites gives 25Hz but I guess 4 constellations is too much.

Try the code in this branch -https://github.com/anchit92/ESP32-RaceBox-mini-Emulator/tree/feature/GNSS_config_fix
Need to figure out the documentation and run it through a couple of events before merging. Even though the code change is minor, I'd rather not break that informal rule.

anchit92, 2025-07-22:
https://github.com/anchit92/ESP32-RaceBox-mini-Emulator/pull/11 addresses this i'll close this after that PR is merged

anchit92, 2025-07-30:
[w](https://github.com/anchit92/ESP32-RaceBox-mini-Emulator/pull/11) Merged

Closed 2025-07-30.

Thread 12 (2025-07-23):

Version with battery?

nbdnnm, 2025-07-23:
Hi @anchit92

Do you think it would work if, instead of the ESP32 from your manual, I use something like [this](https://www.aliexpress.com/item/1005008772275934.html)

Or is there a plan to make a version with an internal battery?

anchit92, 2025-07-24:
That board work fine, you'd have to redesign the case to accommodate for that board.

But no batteries. I don't want to be responsible for suspect LiPo batteries burning up someones car.
I'm not going to merge or link to any battery related stuff here either.

If you'd like to take this on your walks you can either use a generic usb power pack or just use a c to c cable and power it off your phone, I do that and it works fine.

Closed 2025-07-24.

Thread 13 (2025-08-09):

Add support for another GPS packaging — 18.30mm (aka 20mm)

SAGV, 2025-08-09:
Hey hey,

First of all — huge thanks for the project, I assembled it, and it works well. Still yet to be tested on a real track but street tests are OK.

I used this cheaper GPS module from AliExpress (and just now realised that it's actually might be only 10GHz):

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

However, two findings:

A). It also works just fine and is very moderately priced — €13, with the whole setup of about ~20€. Precision is probably less. Though. I recommend reading the specs before ordering.
B). This and many other AliExpress chips come in 20mm packaging which actually ended up being 18.30mm packaging in real life.

I did a monkey-fix on the original STLs like this:

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

However, might be a good idea to add an official 3rd version of the cover?

This is how the end result looks like:

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

P. S. Also, one more finding. For me MPU6050 didn't want to work when soldered from the top of the ESP32. I re-soldered it twice, and it just couldn't see the MPU6050. However, soldering it to the actual legs of ESP32 on the bottom did the job. I am not sure why.

anchit92, 2025-08-11:
@SAGV I also just noticed your refresh rate is like .2Hz in the image, check the serial log and see what sort of rates you're getting from the GPS module. try just using one system, some gps modules dont like it if you add more than 1 and they drop their update rate when you enable multiple constellations.

SAGV, 2025-08-12:
Hmm, strange. Refresh rate indeed is about 0.6-1.6Hz, and doesn't go any higher. I've disabled everything but GPS.

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

Soo normally, should it be 10-25Hz? If so, I'll try to order a non aliexpress module and see how it looks…

anchit92, 2025-08-12:
Ok so that debug is to see where the bottleneck is, and its saying that the gps is giving data at that rate and the bluetooth stack is outputting at the same rate, so we're just not getting enough data from the gps module,

its possible that the library cant reconfigure the refresh rate for some reason. could be that the library doesn't quite support the ublox chip(?). Maybe the v3 of the library supports it, could be an enhancement to use that library instead but they changed some code from under me while i was developing this so i went back to v2.

At boot it gives an output of what all it could or couldn't configure. That might give you more insights.

anchit92, 2025-08-19:
@SAGV i couldnt help but notice that the the module youre using has 5Hz refresh rate according to this documentation-https://micoair.com/gps_m10g-5883/

I'm thinking about implementing a retry to start the refresh rate at 25hz then trying 20,18,15,10,5,1 and stopping whenever it can configure the navigation rate succesfully.

does your module fail loudly when the code trys to set the navigation frequency at 25Hz?

SAGV, 2025-08-20:
I'll play with it later this week. I also just received another module which is linked in the readme and officially works at 25GHz, so I'll now have it to compare the behaviour.

anchit92, 2025-08-22:
The original issue is resolved in https://github.com/anchit92/ESP32-RaceBox-mini-Emulator/pull/15 .

Closed 2025-09-01.

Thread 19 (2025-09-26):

Suggestion: clarify this project is not affiliated with RaceBox

pfichtner, 2025-09-26:
I wanted to flag a potential intellectual property concern. According to [RaceBox’s Terms and Conditions](https://www.racebox.pro/info/terms-and-conditions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) RaceBox and the RaceBox logo are copyrighted, and RaceBox-branded products and materials are their intellectual property. Users are not allowed to reproduce, publish, or imply endorsement of RaceBox products without explicit permission.

The firmware already allows users to customize the device name, so this would mainly reduce any confusion or potential IP concerns without affecting functionality.

Suggested disclaimer wording:

`Disclaimer: This project is independent and open-source. It is not affiliated with, endorsed by, or officially connected to RaceBox. The name “RaceBox Mini” is used only to describe compatibility.`

Thanks for considering!

anchit92, 2025-09-29:
Yeah, that's why I'm dragging my feet a little on the RaceBox app issue.
Fixed in
8f5b0862b7d8b3bdf8adf16b9465193a4afe3cf2

Closed 2025-09-29.

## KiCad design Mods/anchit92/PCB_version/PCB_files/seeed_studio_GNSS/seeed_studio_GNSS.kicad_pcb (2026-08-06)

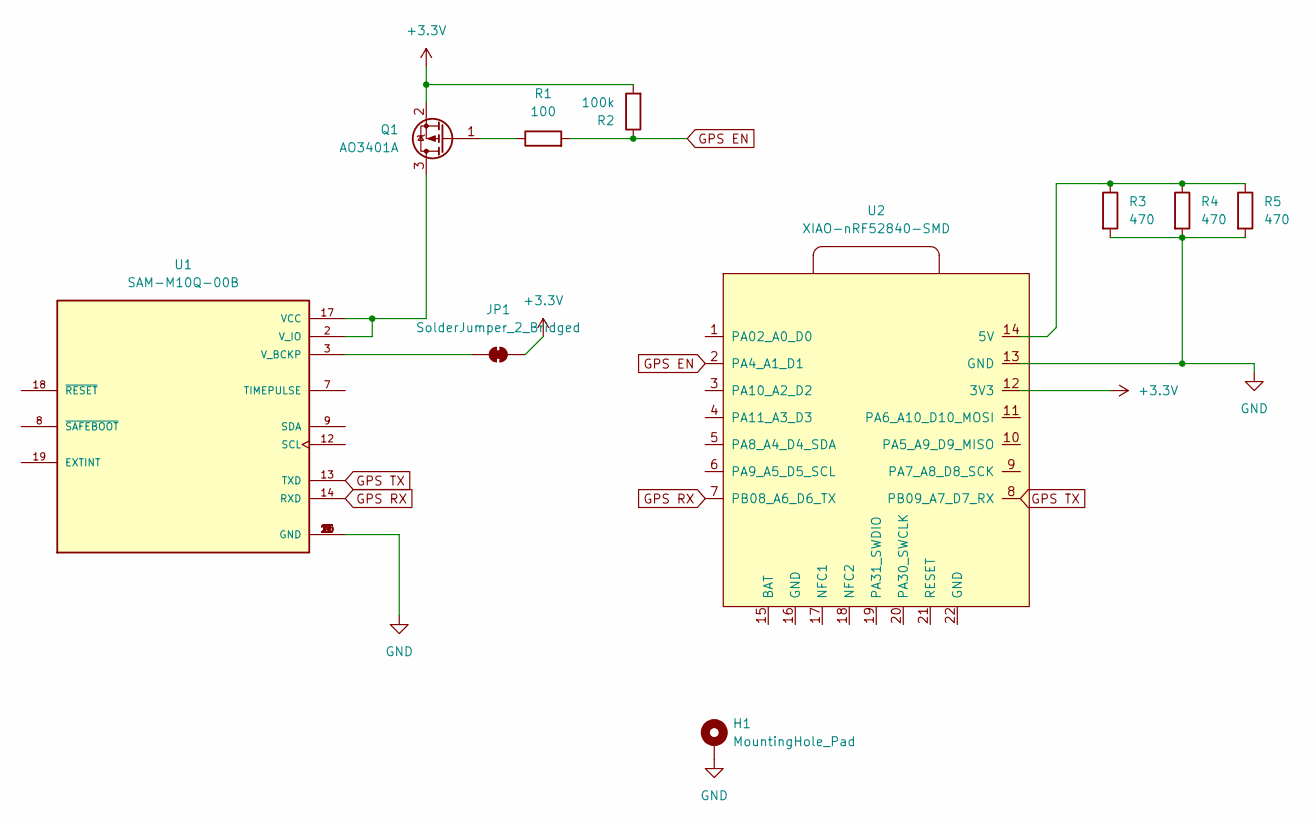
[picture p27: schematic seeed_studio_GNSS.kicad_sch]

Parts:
H1: MountingHole_Pad; MountingHole_3.2mm_M3_DIN965_Pad
JP1: SolderJumper_2_Bridged; SolderJumper-2_P1.3mm_Bridged_Pad1.0x1.5mm
Q1: AO3401A; SOT-23
R1: 100; R_0603_1608Metric
R2: 100k; R_0603_1608Metric
R3, R4, R5: 470; R_0603_1608Metric
U1: SAM-M10Q-00B; XCVR_SAM-M10Q-00B; PARTREV R03
U2: XIAO-nRF52840-SMD

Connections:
+3.3V: JP1.2 (B), Q1.2 (S), R2.2, U2.12 (3V3)
GND: H1.1, R3.2, R4.2, R5.2, U1.1 (GND), U1.4 (GND), U1.5 (GND), U1.6 (GND), U1.10 (GND), U1.11 (GND), U1.15 (GND), U1.16 (GND), U1.20 (GND), U2.13 (GND)
GPS EN: R1.2, R2.1, U2.2 (PA4_A1_D1)
GPS RX: U1.14 (RXD), U2.7 (PB08_A6_D6_TX)
GPS TX: U1.13 (TXD), U2.8 (PB09_A7_D7_RX)
unnamed: JP1.1 (A), U1.3 (V_BCKP)
unnamed: Q1.3 (D), U1.2 (V_IO), U1.17 (VCC)
unnamed: Q1.1 (G), R1.1
unnamed: R3.1, R4.1, R5.1, U2.14 (5V)

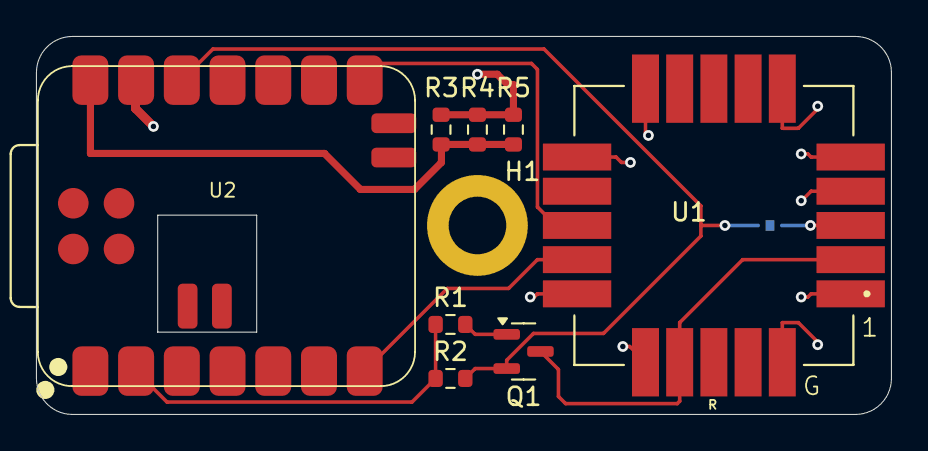
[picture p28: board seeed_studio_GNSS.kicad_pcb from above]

Board: 2 copper layers, 47.5 x 21.0 mm, 10 parts (1 on the bottom side), 9 nets.

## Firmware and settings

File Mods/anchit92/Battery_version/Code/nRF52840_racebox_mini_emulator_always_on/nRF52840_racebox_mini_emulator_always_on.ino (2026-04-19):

#include <Adafruit_TinyUSB.h>
#include <LSM6DS3.h>
#include <SparkFun_u-blox_GNSS_Arduino_Library.h>
#include <Wire.h>
#include <bluefruit.h>
#include <nrf_soc.h>

// ============================================================================
// --- USER CUSTOMIZATION  ---
// ============================================================================

// --- BLE Branding ---
#define SERIAL_NUM "0123456789" // The unique 10-digit serial

// (DO NOT CHANGE THESE: Required for RaceBox Application compatibility)
#define DEVICE_NAME "RaceBox Mini " SERIAL_NUM // Auto-synced Name
#define MANUFACTURER "RaceBox"
#define FIRMWARE_VER "3.3"

// --- GPS Performance ---
#define MAX_NAVIGATION_RATE 25 // 25Hz: Max rate for RaceBox Mini protocol
#define GPS_BAUD 115200        // High speed for 25Hz data
#define FACTORY_GPS_BAUD 9600  // Default for cold modules

#define SYSTEM_RATE_REPORT_MS 5000 // Interval for Serial stats reporting

// --- Power & Efficiency ---
#define EXPECT_BATTERY true // Set to false to force USB-only No-Battery mode
#define GPS_HOT_TIMEOUT_MS 900000 // 15 Minutes (Stay powered after disconnect)
#define DEEP_SLEEP_DAYS 1         // Safety net before absolute shutdown
#define ENABLE_DEEP_SLEEP false   // Usually false for standard RaceBox usage
#define FAST_ADV_INTERVAL 160 // 100ms: Fast discovery for apps (160 * 0.625ms)
#define ECO_ADV_INTERVAL                                                       \
  2000 // 1250ms: Extremely low power (2000 * 0.625ms = 1.25s latency to
       // connect)
#define LOOP_SLEEP 1000 // 1000ms delay for the main loop iteration while idle
#define SLEEP_WHILE_CHARGING                                                   \
  true // Allow Light Sleep even when plugged in Set false to force high power
       // mode when plugged in
#define LOW_POWER_BT_TX_POWER 0 // dBm for low power consumption

// --- GNSS Constellation Toggle ---
#define ENABLE_GNSS_GPS
#define ENABLE_GNSS_GALILEO
// #define ENABLE_GNSS_GLONASS
// #define ENABLE_GNSS_BEIDOU
// #define ENABLE_GNSS_SBAS
// #define ENABLE_GNSS_QZSS

// --- Hardware Version ---
// Uncomment the line below if using the custom PCB version where
// the GPS_EN_PIN logic is inverted. (For PCB: LOW = ON, HIGH = OFF)
// #define PCB_VERSION

// ============================================================================
// ---  HARDWARE MAPPINGS ---
// ============================================================================

#define GPS_EN_PIN D1      // GPS Power Enable Rail
#define PIN_VBAT_ENABLE 14 // Battery Read Enable
#define PIN_HICHG 22       // Charge Speed (LOW=100mA)
#define PIN_CHG 23         // Charge Indicator (LOW=Charging)
#define ACCEL_INT_PIN PIN_LSM6DS3TR_C_INT1

// ============================================================================
// ---  GLOBAL SYSTEM STATE ---
// ============================================================================

SFE_UBLOX_GNSS myGNSS;
LSM6DS3 IMU(I2C_MODE, 0x6A);

// System Flags
bool deviceConnected = false;
bool gpsEnabled = false;
bool imuEnabled = false;
bool pendingConfig = false;
bool lastChargingState = false;
bool lastPluggedInState = false;
bool batteryConnected = true;
uint8_t currentBatteryPercentage = 100;
float batteryMultiplier = 3.0; // Voltage divider 1/3

// Global State
bool isCritical = false;
bool isNoBatteryMode = false;
int GPSFixType = 0;

// Timing Trackers
unsigned long lastDisconnectTime = 0;
unsigned long lastActivityTime = 0;
unsigned long lastGpsRateCheckTime = 0;
unsigned int gpsUpdateCount = 0;
unsigned int gnssUpdateCount = 0;

// Filter/IMU State (Now using hardware filtering)
float imu_ax = 0, imu_ay = 0, imu_az = 0;
float imu_gx = 0, imu_gy = 0, imu_gz = 0;

// BLE Core Objects
const uint8_t RACEBOX_SERVICE_UUID[] = {0x9E, 0xCA, 0xDC, 0x24, 0x0E, 0xE5,
                                        0xA9, 0xE0, 0x93, 0xF3, 0xA3, 0xB5,
                                        0x01, 0x00, 0x40, 0x6E};
const uint8_t RACEBOX_TX_UUID[] = {0x9E, 0xCA, 0xDC, 0x24, 0x0E, 0xE5,
                                   0xA9, 0xE0, 0x93, 0xF3, 0xA3, 0xB5,
                                   0x03, 0x00, 0x40, 0x6E};
const uint8_t RACEBOX_RX_UUID[] = {0x9E, 0xCA, 0xDC, 0x24, 0x0E, 0xE5,
                                   0xA9, 0xE0, 0x93, 0xF3, 0xA3, 0xB5,
                                   0x02, 0x00, 0x40, 0x6E};
const uint8_t RACEBOX_GNSS_UUID[] = {0x9E, 0xCA, 0xDC, 0x24, 0x0E, 0xE5,
                                     0xA9, 0xE0, 0x93, 0xF3, 0xA3, 0xB5,
                                     0x04, 0x00, 0x40, 0x6E};

BLEService rbService(RACEBOX_SERVICE_UUID);
BLECharacteristic rbTx(RACEBOX_TX_UUID);
BLECharacteristic rbRx(RACEBOX_RX_UUID);
BLECharacteristic rbGnss(RACEBOX_GNSS_UUID);

BLEService disService(UUID16_SVC_DEVICE_INFORMATION);
BLECharacteristic disModel(UUID16_CHR_MODEL_NUMBER_STRING);
BLECharacteristic disSerial(UUID16_CHR_SERIAL_NUMBER_STRING);
BLECharacteristic disFirmware(UUID16_CHR_FIRMWARE_REVISION_STRING);
BLECharacteristic disHardware(UUID16_CHR_HARDWARE_REVISION_STRING);
BLECharacteristic disManuf(UUID16_CHR_MANUFACTURER_NAME_STRING);

const int OnboardledPin = LED_BLUE;

// --- Helper Utilities ---
template <typename T>
void writeLittleEndian(uint8_t *buffer, int offset, T value) {
  memcpy(buffer + offset, &value, sizeof(T));
}

void calculateChecksum(uint8_t *payload, uint16_t len, uint8_t cls, uint8_t id,
                       uint8_t *ckA, uint8_t *ckB) {
  *ckA = *ckB = 0;
  *ckA += cls;
  *ckB += *ckA;
  *ckA += id;
  *ckB += *ckA;
  *ckA += len & 0xFF;
  *ckB += *ckA;
  *ckA += len >> 8;
  *ckB += *ckA;
  for (uint16_t i = 0; i < len; i++) {
    *ckA += payload[i];
    *ckB += *ckA;
  }
}

bool isCharging() { return digitalRead(PIN_CHG) == LOW; }

// Calibration Table
struct VoltagePoint {
  float voltage;
  uint8_t percentage;
};

const VoltagePoint batteryMap[] = {
    {4.13, 100}, {4.12, 98}, {4.10, 95}, {4.05, 92}, {4.00, 88}, {3.98, 85},
    {3.96, 82},  {3.94, 79}, {3.92, 75}, {3.90, 72}, {3.88, 68}, {3.85, 65},
    {3.82, 62},  {3.78, 55}, {3.72, 45}, {3.68, 35}, {3.63, 25}, {3.58, 18},

    {3.50, 10},  {3.35, 5},  {3.20, 0}};

const uint8_t mapSize = sizeof(batteryMap) / sizeof(VoltagePoint);

// Lookup Function
float getRawPercentage() {
  float v = getBatteryVoltage(); // Your 16-sample average function
  if (v >= batteryMap[0].voltage)
    return 100.0;
  if (v <= batteryMap[mapSize - 1].voltage)
    return 0.0;

  for (int i = 0; i < mapSize - 1; i++) {
    if (v <= batteryMap[i].voltage && v > batteryMap[i + 1].voltage) {
      float vHigh = batteryMap[i].voltage;
      float vLow = batteryMap[i + 1].voltage;
      uint8_t pHigh = batteryMap[i].percentage;
      uint8_t pLow = batteryMap[i + 1].percentage;
      return pLow + (v - vLow) * (pHigh - pLow) / (vHigh - vLow);
    }
  }
  return 0.0;
}

// State Update
void updateBatteryState() {
  float rawPct = getRawPercentage();
  float currentV = getBatteryVoltage();

  // Set Critical Flag (e.g., below 3.35V / 10%)
  isCritical = (currentV < 3.35);

  // Directly map raw percentage to current battery percentage
  currentBatteryPercentage = (uint8_t)(rawPct + 0.5);
}

bool isPluggedIn() {
  // Check if USB power is detected
  return NRF_POWER->USBREGSTATUS & POWER_USBREGSTATUS_VBUSDETECT_Msk;
}

float getBatteryVoltage() {
  digitalWrite(PIN_VBAT_ENABLE, LOW); // Enable divider
  delay(1);

  uint32_t sum = 0;
  for (int i = 0; i < 8; i++) {
    sum += analogRead(PIN_VBAT);
    delayMicroseconds(50);
  }
  float adcCount = (float)sum / 8.0;
  float voltage = (batteryMultiplier * 3.6 * adcCount / 4096);

  if (!isCharging() && !isPluggedIn()) {
    digitalWrite(PIN_VBAT_ENABLE, HIGH);
  }
  return voltage;
}

// ============================================================================
// ---  SENSOR PROCESSING MODULES ---
// ============================================================================

// Assemble and transmit the proprietary RaceBox Mini protocol packet

void sendRaceboxPacket() {
  if (!deviceConnected || myGNSS.packetUBXNAVPVT == NULL)
    return;

  uint8_t payload[80] = {0};
  uint8_t packet[88] = {0};
  auto *data = &myGNSS.packetUBXNAVPVT->data;

  // Time and Resolution
  writeLittleEndian(payload, 0, data->iTOW);
  writeLittleEndian(payload, 4, data->year);
  writeLittleEndian(payload, 6, data->month);
  writeLittleEndian(payload, 7, data->day);
  writeLittleEndian(payload, 8, data->hour);
  writeLittleEndian(payload, 9, data->min);
  writeLittleEndian(payload, 10, data->sec);

  // Status and Accuracy
  uint8_t val = 0;
  if (data->valid.bits.validDate)
    val |= (1 << 0);
  if (data->valid.bits.validTime)
    val |= (1 << 1);
  if (data->valid.bits.fullyResolved)
    val |= (1 << 2);
  writeLittleEndian(payload, 11, val);
  writeLittleEndian(payload, 12, data->tAcc);
  writeLittleEndian(payload, 16, data->nano);
  writeLittleEndian(payload, 20, data->fixType);

  // Fix and Info Flags
  uint8_t fixFlags = 0;
  if (data->fixType == 3)
    fixFlags |= (1 << 0);
  if (myGNSS.getHeadVehValid())
    fixFlags |= (1 << 5);
  writeLittleEndian(payload, 21, fixFlags);

  uint8_t dtFlags = 0;
  if (data->valid.bits.validTime)
    dtFlags |= (1 << 5);
  if (data->valid.bits.validDate)
    dtFlags |= (1 << 6);
  if (data->valid.bits.validTime && data->valid.bits.fullyResolved)
    dtFlags |= (1 << 7);
  writeLittleEndian(payload, 22, dtFlags);

  // Position, Speed, and Heading
  writeLittleEndian(payload, 23, data->numSV);
  writeLittleEndian(payload, 24, (int32_t)data->lon);
  writeLittleEndian(payload, 28, (int32_t)data->lat);
  writeLittleEndian(payload, 32, (int32_t)data->height);
  writeLittleEndian(payload, 36, (int32_t)data->hMSL);
  writeLittleEndian(payload, 40, (uint32_t)data->hAcc);
  writeLittleEndian(payload, 44, (uint32_t)data->vAcc);
  writeLittleEndian(payload, 48, (int32_t)data->gSpeed);
  writeLittleEndian(payload, 52, (int32_t)data->headMot);
  writeLittleEndian(payload, 56, (uint32_t)data->sAcc);
  writeLittleEndian(payload, 60, (uint32_t)data->headAcc);
  writeLittleEndian(payload, 64, (uint16_t)data->pDOP);

  // Fix Quality and Misc
  if (data->fixType < 2)
    writeLittleEndian(payload, 66, (uint8_t)(1 << 0));

  uint8_t batPct = currentBatteryPercentage & 0x7F;
  if (isCharging())
    batPct |= 0x80;
  writeLittleEndian(payload, 67, batPct);

  // Physical Sensors (Hardware Filtered)
  writeLittleEndian(payload, 68, (int16_t)(imu_ax * 1000.0));
  writeLittleEndian(payload, 70, (int16_t)(imu_ay * 1000.0));
  writeLittleEndian(payload, 72, (int16_t)(imu_az * 1000.0));
  writeLittleEndian(payload, 74, (int16_t)(imu_gx * 100.0));
  writeLittleEndian(payload, 76, (int16_t)(imu_gy * 100.0));
  writeLittleEndian(payload, 78, (int16_t)(imu_gz * 100.0));

  // Protocol Wrapper
  packet[0] = 0xB5;
  packet[1] = 0x62;
  packet[2] = 0xFF;
  packet[3] = 0x01;
  packet[4] = 80;
  packet[5] = 0;
  memcpy(packet + 6, payload, 80);

  uint8_t ckA, ckB;
  calculateChecksum(payload, 80, 0xFF, 0x01, &ckA, &ckB);
  packet[86] = ckA;
  packet[87] = ckB;

  if (rbTx.notify(packet, 88))
    gpsUpdateCount++;
}

// Background polling and data routing for the u-blox module
void processGNSS() {
  if (!gpsEnabled)
    return;
  myGNSS.checkUblox();

  if (myGNSS.getPVT()) {
    static uint32_t lastITOW = 0;
    uint32_t currentITOW = myGNSS.packetUBXNAVPVT->data.iTOW;
    GPSFixType = myGNSS.packetUBXNAVPVT->data.fixType;
    if (currentITOW != lastITOW) {
      lastITOW = currentITOW;
      gnssUpdateCount++;
      sendRaceboxPacket();
    }
  }

  // Backup Recovery: Ensure background processing during data stalls
  static unsigned long lastValidData = 0;
  if (myGNSS.getPVT())
    lastValidData = millis();
  if (deviceConnected && (millis() - lastValidData > 2000))
    myGNSS.checkUblox();
}

// IMU Sampling (Hardware filters handle smoothing)
void processIMU() {
  if (!imuEnabled)
    return;

  imu_ax = IMU.readFloatAccelX();
  imu_ay = IMU.readFloatAccelY();
  imu_az = IMU.readFloatAccelZ();
  imu_gx = IMU.readFloatGyroX();
  imu_gy = IMU.readFloatGyroY();
  imu_gz = IMU.readFloatGyroZ();
}

// ============================================================================
// --- 🔋 POWER & SYSTEM MANAGEMENT ---
// ============================================================================
bool resetGpsBaudRate() {
  Serial.println("🔍 Deep Scanning for GNSS activity...");
  long bauds[] = {9600, 38400, 115200, 57600};

  for (int b = 0; b < 4; b++) {
    Serial.print("Checking ");
    Serial.print(bauds[b]);
    Serial.print(" baud: ");

    Serial1.end();
    delay(100);
    Serial1.begin(bauds[b]);

    // Sniff for raw activity first (for 1.5 seconds)
    unsigned long sniffStart = millis();
    bool activity = false;
    while (millis() - sniffStart < 1500) {
      if (Serial1.available()) {
        activity = true;
        break;
      }
    }

    if (activity) {
      Serial.print("RAW DATA DETECTED! ");

      // Clear the buffer of NMEA messages
      delay(200);
      while (Serial1.available())
        Serial1.read();

      // Try the library sync
      if (myGNSS.begin(Serial1)) {
        Serial.println("✅ UBX Protocol Synced!");

        if (bauds[b] != GPS_BAUD) {
          Serial.print("Elevating to ");
          Serial.print(GPS_BAUD);
          Serial.println(" baud...");
          myGNSS.setSerialRate(GPS_BAUD);
          delay(100);
          Serial1.end();
          delay(100);
          Serial1.begin(GPS_BAUD);
        }

        myGNSS.saveConfiguration();
        return true;
      } else {
        Serial.println("❌ Bytes received, but u-blox library could not sync "
                       "(Check protocol/clones).");
      }
    } else {
      Serial.println("Silent.");
    }

    Serial1.end();
  }

  Serial.println("❌ GNSS not detected. Check VCC voltage or TX/RX wiring.");
  return false;
}

bool configureGPS() {
  if (!pendingConfig)
    return false;
  Serial.println("⚙️ Syncing GPS Settings...");
  Serial1.begin(GPS_BAUD);

  bool detected = false;
  for (int i = 0; i < 3; i++) {
    if (myGNSS.begin(Serial1)) {
      detected = true;
      break;
    }
    delay(20);
  }

  if (!detected) {
    return resetGpsBaudRate();
  }

  myGNSS.setPortOutput(COM_PORT_UART1, COM_TYPE_UBX);
  myGNSS.setAutoPVT(true);

  // High-Performance Track Dynamics Configuration
  // Used Airborne2g since passenger track cars (GT3/GT4) easily exceed 1g
  // braking/cornering and we do not want the navigation engine to "smooth" or
  // reject these forces as anomalies.
  myGNSS.setDynamicModel(DYN_MODEL_AIRBORNE2g);

  // Disable low-pass filters to prevent time-domain lag on braking and
  // acceleration telemetry
  myGNSS.setVal8(0x10220001,
                 0); // CFG-ODO-OUTLPVEL: Disable speed (3D) low-pass filter
  myGNSS.setVal8(
      0x10220002,
      0); // CFG-ODO-OUTLPCOG: Disable course over ground low-pass filter

  // Ensure static hold is explicitly disabled so slow pit-lane creeping isn't
  // frozen at 0mph
  myGNSS.setVal8(0x20250038,
                 0); // CFG-MOT-GNSSSPEED_THRS: Static hold threshold = 0

  // Enable Super-S (Automatic Mode) to compensate for any signal attenuation
  // through the ABS enclosure
  myGNSS.setVal8(0x201100D5, 1); // CFG-NAVSPG-SIGATTCOMP: 1 = Automatic

  // For SAM-M10Q 25Hz, we MUST explicitly disable other constellations FIRST
  // before increasing the navigation frequency, otherwise the module rejects
  // it.
#ifdef ENABLE_GNSS_GPS
  myGNSS.enableGNSS(true, SFE_UBLOX_GNSS_ID_GPS);
#else
  myGNSS.enableGNSS(false, SFE_UBLOX_GNSS_ID_GPS);
#endif

#ifdef ENABLE_GNSS_GALILEO
  myGNSS.enableGNSS(true, SFE_UBLOX_GNSS_ID_GALILEO);
#else
  myGNSS.enableGNSS(false, SFE_UBLOX_GNSS_ID_GALILEO);
#endif

#ifdef ENABLE_GNSS_GLONASS
  myGNSS.enableGNSS(true, SFE_UBLOX_GNSS_ID_GLONASS);
#else
  myGNSS.enableGNSS(false, SFE_UBLOX_GNSS_ID_GLONASS);
#endif

#ifdef ENABLE_GNSS_BEIDOU
  myGNSS.enableGNSS(true, SFE_UBLOX_GNSS_ID_BEIDOU);
#else
  myGNSS.enableGNSS(false, SFE_UBLOX_GNSS_ID_BEIDOU);
#endif

#ifdef ENABLE_GNSS_SBAS
  myGNSS.enableGNSS(true, SFE_UBLOX_GNSS_ID_SBAS);
#else
  myGNSS.enableGNSS(false, SFE_UBLOX_GNSS_ID_SBAS);
#endif

#ifdef ENABLE_GNSS_QZSS
  myGNSS.enableGNSS(true, SFE_UBLOX_GNSS_ID_QZSS);
#else
  myGNSS.enableGNSS(false, SFE_UBLOX_GNSS_ID_QZSS);
#endif

  // Now that extraneous constellations are OFF, we can safely request 25Hz
  myGNSS.setNavigationFrequency(MAX_NAVIGATION_RATE);

  pendingConfig = false;
  Serial.println("✅ Configuration complete.");
  return true;
}

// Re-configure advertising with specific power and interval
// Standard Adafruit/Seeed Bluefruit requires re-adding data to update the
// packet-reported TX power
void setupAdvertising(int8_t power, uint16_t interval) {
  if (deviceConnected)
    return;

  Bluefruit.Advertising.stop();
  Bluefruit.setTxPower(power);
  Bluefruit.Advertising.setInterval(interval, interval + 200);

  // Clear and Rebuild Advertising Data
  // This ensures the TX Power field in the packet matches the new hardware
  // power
  Bluefruit.Advertising.clearData();
  Bluefruit.Advertising.addFlags(BLE_GAP_ADV_FLAGS_LE_ONLY_GENERAL_DISC_MODE);
  Bluefruit.Advertising.addTxPower();

  // NOTE: We keep the Service UUIDs in the primary advertisement for
  // compatibility with the RaceBox application.
  Bluefruit.Advertising.addService(rbService);
  Bluefruit.Advertising.addService(disService);

  // Scan Response only contains the Name to keep it simple
  Bluefruit.ScanResponse.clearData();
  Bluefruit.ScanResponse.addName();

  Bluefruit.Advertising.start(0);
}

void enableGPS() {
  if (gpsEnabled)
    return;
#ifdef PCB_VERSION
  digitalWrite(GPS_EN_PIN, LOW);
#else
  digitalWrite(GPS_EN_PIN, HIGH);
#endif
  gpsEnabled = true;
  delay(100);
  if (!deviceConnected) {
    setupAdvertising(0, FAST_ADV_INTERVAL);
  }
}

void disableGPS() {
  GPSFixType = 0;
  pendingConfig = true;
#ifdef PCB_VERSION
  digitalWrite(GPS_EN_PIN, HIGH);
#else
  digitalWrite(GPS_EN_PIN, LOW);
#endif
  gpsEnabled = false;
  // Serial1.end(); // Dont uncomment this, it causes a 4mA power leak
  // pinMode(PIN_SERIAL1_TX, INPUT_PULLDOWN);
  // pinMode(PIN_SERIAL1_RX, INPUT_PULLDOWN);

  digitalWrite(LED_RED, HIGH);
  digitalWrite(LED_GREEN, HIGH);
  if (!deviceConnected) {
    setupAdvertising(LOW_POWER_BT_TX_POWER, ECO_ADV_INTERVAL);
  }
}

void enableIMU() {
  if (imuEnabled)
    return;
  IMU.settings.accelSampleRate = 1660; // 1.6kHz for hardware filtering
  IMU.settings.gyroSampleRate = 1660;
  IMU.settings.accelRange = 8;
  IMU.settings.gyroRange = 500;

  if (IMU.begin() != 0)
    return;

  // --- HARDWARE FILTER CONFIGURATION ---
  // Gyroscope: Enable LPF1 (Register 0x13, Bit 1)
  IMU.writeRegister(0x13, 0x02);
  // Gyroscope: Set LPF1 Bandwidth (Register 0x15, Bits 1:0 = 01)
  IMU.writeRegister(0x15, 0x01);
  // Accelerometer: Enable LPF2 (Register 0x17, Bit 0) and Set HPCF (Bits 6:5 =
  // 01 for ODR/50)
  IMU.writeRegister(0x17, 0x21);

  imuEnabled = true;
}

void disableIMU() {
  if (!imuEnabled)
    return;
  // Explicitly power down the sensor registers
  IMU.writeRegister(LSM6DS3_ACC_GYRO_CTRL1_XL, 0x00);
  IMU.writeRegister(LSM6DS3_ACC_GYRO_CTRL2_G, 0x00);
  imuEnabled = false;
}

void powerDownSensors() {
  // Soft disable
  if (gpsEnabled)
    disableGPS();
  if (imuEnabled)
    disableIMU();

  // Enforce hardware shutdown state to prevent parasitic leaks or pin sync
  // issues
#ifdef PCB_VERSION
  digitalWrite(GPS_EN_PIN, HIGH);
#else
  digitalWrite(GPS_EN_PIN, LOW);
#endif
}
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
void loop() {
  bool idle = !deviceConnected && !gpsEnabled && !imuEnabled;

  if (idle && !isNoBatteryMode) {
    manageBatterySampling(); // Always track battery to prevent deep sleep death
    if (isPluggedIn()) {
      reportSystemStats();
    }
    managePower();
    powerDownSensors(); // Enforce shutdown state while in light sleep
    // Sleep in small chunks so we can wake up instantly when a BLE connection
    // occurs
    for (int i = 0; i < LOOP_SLEEP; i += 100) {
      if (deviceConnected)
        break;
      delay(100);
    }
    return;
  }

  processGNSS();
  processIMU();
  managePower();
  reportSystemStats();
  manageBatterySampling();
  updateLEDs(GPSFixType);
  delay(1);
}

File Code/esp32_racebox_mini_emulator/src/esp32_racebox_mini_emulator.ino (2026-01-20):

#include <Adafruit_MPU6050.h>
#include <Adafruit_Sensor.h>
#include <Wire.h>
#include <SparkFun_u-blox_GNSS_Arduino_Library.h>
#include <BLEDevice.h>
#include <BLEServer.h>
#include <BLEUtils.h>
#include <BLE2902.h>
#include <string>
#include <vector>

// --- GPS Configuration ---
#define GPS_RX_PIN 16
#define GPS_TX_PIN 17
#define GPS_BAUD 115200
#define FACTORY_GPS_BAUD 9600
#define MAX_NAVIGATION_RATE 25

SFE_UBLOX_GNSS myGNSS;
HardwareSerial GPS_Serial(2);
// --- Enable GNSS constellations ---
// The specific constellations available and how many you can turn on depend on your u-blox module 
// check this out for which constellations to enable https://app.qzss.go.jp/GNSSView/gnssview.html

#define ENABLE_GNSS_GPS
#define ENABLE_GNSS_GALILEO
// #define ENABLE_GNSS_GLONASS
// #define ENABLE_GNSS_BEIDOU
// #define ENABLE_GNSS_SBAS
// #define ENABLE_GNSS_QZSS

constexpr const char* rawDeviceName = "RaceBox Mini 0123456789";

constexpr unsigned long MAX_ALLOWED = 3999999999;

constexpr unsigned long parseSuffix(const char* name) {
    unsigned long val = 0;
    // The suffix starts at index 13 (after "RaceBox Mini ")
    for (int i = 13; i < 23; ++i) {
        val = val * 10 + (name[i] - '0');
    }
    return val;
}

static_assert(parseSuffix(rawDeviceName) <= MAX_ALLOWED, 
              "ERROR: RaceBox Mini number cannot exceed 3999999999 for compatibility with the official RaceBox App");

const String deviceName = rawDeviceName;

const int OnboardledPin = 2;

Adafruit_MPU6050 mpu;
const unsigned long AccelSampleInterval = 10; // 10ms = 100Hz
// --- Smoothing Configuration ---
// alpha = 1.0: No filtering (raw data)
// alpha = 0.5: 50% current reading, 50% previous (moderate)
// alpha = 0.8: Very snappy, just kills high-frequency "buzz"
float accelAlpha = 0.8; 
float gyroAlpha = 0.8; 
// Storage for the filtered values
float filtered_ax = 0, filtered_ay = 0, filtered_az = 0;
float filtered_gx = 0, filtered_gy = 0, filtered_gz = 0;

// --- BLE Configuration ---
const char* const RACEBOX_SERVICE_UUID = "6E400001-B5A3-F393-E0A9-E50E24DCCA9E";
const char* const RACEBOX_CHARACTERISTIC_RX_UUID = "6E400002-B5A3-F393-E0A9-E50E24DCCA9E";
const char* const RACEBOX_CHARACTERISTIC_TX_UUID = "6E400003-B5A3-F393-E0A9-E50E24DCCA9E";

BLEServer *pServer = NULL;
BLECharacteristic *pCharacteristicTx = NULL;
BLECharacteristic *pCharacteristicRx = NULL;
bool deviceConnected = false;
bool oldDeviceConnected = false;

// --- Packet Timing ---
unsigned long lastPacketSendTime = 0;
const unsigned long PACKET_SEND_INTERVAL_MS = 40;
unsigned long lastGpsRateCheckTime = 0;
unsigned int gpsUpdateCount = 0;
const unsigned long GPS_RATE_REPORT_INTERVAL_MS = 5000;
unsigned int gnssUpdateCount = 0;


// --- BLE Callbacks ---
class MyServerCallbacks : public BLEServerCallbacks {
  void onConnect(BLEServer *pServer) {
    deviceConnected = true;
    // Request a larger MTU to fit an 88-byte packet + headers in one go
    pServer->updatePeerMTU(pServer->getConnId(), 128); 
    digitalWrite(OnboardledPin, HIGH);
    Serial.println("✅ BLE Client connected & MTU update requested");
  }
  void onDisconnect(BLEServer *pServer) {
    deviceConnected = false;
    digitalWrite(OnboardledPin, LOW);
    Serial.println("❌ BLE Client disconnected");
  }
};

class MyCharacteristicCallbacks : public BLECharacteristicCallbacks {
  void onWrite(BLECharacteristic *pCharacteristic) {
    String rxValue = pCharacteristic->getValue(); 
    
    if (rxValue.length() > 0) {
      Serial.print("📨 Received BLE command: ");
      for (size_t i = 0; i < rxValue.length(); i++) {
        Serial.printf("0x%02X ", (uint8_t)rxValue[i]);
      }
      Serial.println();
    }
  }
};

// --- UBX Packet Construction Helpers ---
void writeLittleEndian(uint8_t* buffer, int offset, uint32_t value) { memcpy(buffer + offset, &value, 4); }
void writeLittleEndian(uint8_t* buffer, int offset, int32_t value)  { memcpy(buffer + offset, &value, 4); }
void writeLittleEndian(uint8_t* buffer, int offset, uint16_t value) { memcpy(buffer + offset, &value, 2); }
void writeLittleEndian(uint8_t* buffer, int offset, int16_t value)  { memcpy(buffer + offset, &value, 2); }
void writeLittleEndian(uint8_t* buffer, int offset, uint8_t value)  { buffer[offset] = value; }
void writeLittleEndian(uint8_t* buffer, int offset, int8_t value)   { buffer[offset] = (uint8_t)value; }

void calculateChecksum(uint8_t* payload, uint16_t len, uint8_t cls, uint8_t id, uint8_t* ckA, uint8_t* ckB) {
  *ckA = *ckB = 0;
  *ckA += cls; *ckB += *ckA;
  *ckA += id; *ckB += *ckA;
  *ckA += len & 0xFF; *ckB += *ckA;
  *ckA += len >> 8; *ckB += *ckA;
  for (uint16_t i = 0; i < len; i++) {
    *ckA += payload[i];
    *ckB += *ckA;
  }
}

void resetGpsBaudRate() {
  Serial.println("Attempting to set Correct Baud Rate");
  GPS_Serial.begin(FACTORY_GPS_BAUD, SERIAL_8N1, GPS_RX_PIN, GPS_TX_PIN);
  delay(500);

  if (!myGNSS.begin(GPS_Serial)) {
    Serial.print("u-blox GNSS not detected at ");
    Serial.print(FACTORY_GPS_BAUD);
    Serial.println(" baud.");
    Serial.print("u-blox GNSS not detected, Check documentation for factory baud rate and/or check your wiring");
    while(1) delay(100);
  } else {
    Serial.print("GNSS detected at ");
    Serial.print(FACTORY_GPS_BAUD);
    Serial.println(" baud!");
  }
  delay(500);

  // Now switch baud rate
  Serial.print("Setting baud rate to ");
  Serial.print(GPS_BAUD);
  Serial.println("...");
  myGNSS.setSerialRate(GPS_BAUD);
  Serial.print("Baud rate changed to ");
  Serial.println(GPS_BAUD);

  GPS_Serial.end();
  delay(100);
  // Re-initialize the serial port at the new baud rate
  GPS_Serial.begin(GPS_BAUD, SERIAL_8N1, GPS_RX_PIN, GPS_TX_PIN);
  delay(500);

  if (!myGNSS.begin(GPS_Serial)) {
    Serial.print("GNSS not detected at ");
    Serial.print(GPS_BAUD);
    Serial.println(" baud.");
    Serial.print("u-blox GNSS not detected, Check documentation for factory baud rate and/or check your wiring");
    while (1) delay(100);
  }
  Serial.print("GNSS detected at ");
  Serial.print(GPS_BAUD);
  Serial.println(" baud! Saving to Flash");
  myGNSS.saveConfiguration(); // Save to flash
  GPS_Serial.end();
}
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

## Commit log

2025-06-28 Improved clearances for printing in PETG/PLA. Still should work well with ABS.
    [Base with gopro mount.3mf, Base.3mf, Button_x2.3mf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]
2025-06-29 Fixed base print orientation Added button with more clearance
    [AXDL_mount.3mf, Base with gopro mount.3mf, Base.3mf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]
2025-07-20 Added no buttons lids
    [Base.3mf, Base_GoPro_mount.3mf, Button_x2.3mf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]
2025-07-20 fix names
    [Lid_16mm_Antenna_GPS_No_Buttons.3mf, Lid_25mm_Antenna_GPS_No_Buttons.3mf]
2025-07-20 Update README.md
    added note about buttons
2025-07-22 Fixed gnss constellations,Cant just turn them all ON without any negative consequences
    [esp32_racebox_mini_emulator.ino]
2025-07-22 Documentation update, kalman filter on IMU data
2025-08-22 Added CAD and STL's for 18mm gps antenna modules
    [Lid 18mm gps no buttons.3mf, Lid 18mm gps.3mf]
2025-08-22 Update esp32_racebox_mini_emulator.ino
    Unintended change.
2026-01-10 Replace Kalman filters with Exponential Moving Average
    Removed Kalman filter implementation for accelerometer and gyroscope. Implemented Exponential Moving Average for sensor data filtering.
    [esp32_racebox_mini_emulator.ino]
2026-01-12 Added Slim Base
    [ESP32 RACEBOX SLIM BASE GOPRO.step, ESP32 RACEBOX SLIM BASE.step, Slim Base GoPro.3mf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]
2026-01-12 Fix print orientation
    [Slim Base GoPro.3mf, Slim Base.3mf]
2026-01-17 Update esp32_racebox_mini_emulator.ino
    Code Cleanup
2026-01-25 Added code for battery version using a seeed studio XIAO nRF52840 Sense
2026-01-25 battery reporting fixes
2026-01-26 Update nRF52840_racebox_mini_emulator_always_on.ino
    Battery Management updates
2026-01-27 more LED states, Bettery Battery Reporting. Fix bug with IMU power management
    [nRF52840_racebox_mini_emulator_always_on.ino]
2026-01-27 More Battery management
2026-01-28 More power optimization
2026-01-29 Added Cad and STL and Readme
    [Base.3mf, GoPro Base.3mf, Lid 18mm gps.3mf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]
2026-01-29 Corrected CAD
    [GoPro Base.3mf, Lig 16mm gps.3mf, nRF52840 RACEBOX Mini v20.step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]
2026-01-29 corrected print orientation
    [Base.3mf, GoPro Base.3mf, Lid 18mm gps.3mf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]
2026-01-29 Lets try this again
    [Base.3mf, GoPro Base.3mf, Lid 18mm gps.3mf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]
2026-01-29 Prusa slicer wont save files in the correct orientation for me? Cura it is
    [Base.3mf, GoPro Base.3mf, Lid 18mm gps.3mf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]
2026-01-29 Added LED states
2026-01-31 Battery% is complicated
2026-01-31 Fixed edge case where if turned on during charging it wont go back to sleep
    [nRF52840_racebox_mini_emulator_always_on.ino]
2026-02-01 Simplify IMU filterring and use the onboard filters to offload from software
2026-02-03 Corrected base orintation more reorganization added extra gps module lid
    [Base.3mf, GoPro Base.3mf, Lid HGLRC M100-5883 gps.3mf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]
2026-02-10 Made mods folder
    [Base.3mf, GoPro Base.3mf, Lid HGLRC M100-5883 gps.3mf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]
2026-02-10 fix folder structure
    [Base.3mf, GoPro Base.3mf, Lid HGLRC M100-5883 gps.3mf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]
2026-02-10 Update README for RaceBox Mini Emulator Battery Version
2026-02-12 Remove INPUT_PULLDOWN from pin 11
    Removed INPUT_PULLDOWN mode from pin 11.
2026-02-15 Reset GPS baud rate in power management
    [nRF52840_racebox_mini_emulator_always_on.ino]
2026-03-13 Refactor battery and GPS management for efficiency
    Updated battery management and GPS handling logic. Enhanced power efficiency and added support for no-battery mode.
2026-03-13 Comment out PCB_VERSION definition
    Comment out the PCB_VERSION definition for flexibility.
2026-03-14 first commit for PCB version
2026-03-14 set default as pcb version
2026-03-14 fix bad git stuff
    [BOM-seeed_studio_GNSS.csv, Base.3mf, GoPro Base.3mf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]
2026-03-14 Revise README with new content and clarifications
    Updated README to include additional information about hardware options, assembly instructions, and firmware setup.
2026-03-14 Update M3 screw specification in README.md
2026-03-15 Update 3D printed case description in README
2026-03-15 Update GNSS Constellations section in README
    Clarified the impact of selecting satellite systems on power usage and refresh rate.
2026-03-16 Revise PCB manufacturing instructions in README
    Updated assembly type description and cost estimate for PCB manufacturing.
2026-03-16 Revise README for clarity and additional details
    Updated README to include additional information on hardware options, assembly instructions, and firmware setup.
2026-03-16 Modify startup LED flash count from 5 to 1
    Changed the LED flash indication from 5 times to 1 time during startup.
2026-03-17 Revise battery specifications in README.md
    Updated battery options in README with alternative sizes.
2026-03-22 Clarify GNSS module orientation in assembly instructions
    Added a note about the orientation of the GNSS module during soldering.
2026-03-25 added vented case
    [Base vented.3mf, GoPro Base Vented.3mf, Lid vented.3mf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]
2026-03-30 added instructions to solder gps
2026-04-19 Improve discoverability from sleep, Simplify Battery % reporting.
2026-08-06 Updated PCB based on experience
    [freerouting.dsn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]
2026-08-07 chore: add KiCad gitignore rules and untrack local/temp files, updated readme
2026-08-31 PCB Step file
    PCB CAD
    [DIY Racebox Emulator PCB.step]
